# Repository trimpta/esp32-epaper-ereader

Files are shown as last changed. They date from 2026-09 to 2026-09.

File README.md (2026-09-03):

# esp32-epaper-ereader

> 🤖 **Disclosure: this project is "vibe coded."** The firmware, converter, simulator, docs, and
> this README were written collaboratively with [Claude](https://claude.com/claude-code) (Anthropic),
> directed and reviewed by a human, without physical access to the target hardware. Nothing here has
> run on a real board yet — see [Status / what needs real-hardware verification](#status--what-needs-real-hardware-verification)
> for the specific things that are reasoned-through rather than measured. Treat pin mappings, driver
> compatibility, and size estimates as a well-researched starting point to verify, not a guarantee.

A DIY EPUB e-reader built on the [CrowPanel ESP32 2.13" E-Paper HMI Display](https://www.elecrow.com/crowpanel-esp32-2-13-e-paper-hmi-display-with-122-250-resolution-black-white-color-driven-by-spi-interface.html)
(ESP32-S3, SSD1680Z/JD79661, 122×250 mono, 8MB flash, no SD slot) — full firmware, a browser-side
EPUB converter, a parametric enclosure, and a **fully-interactive browser simulator** so you can
build and preview the whole reading experience before your hardware even ships.

Not aiming for EPUB spec compliance — CSS, embedded fonts, images, and complex layout are
intentionally dropped. The goal is fast, low-effort page turns on very limited hardware, and a
project you can actually finish.

## The hardware

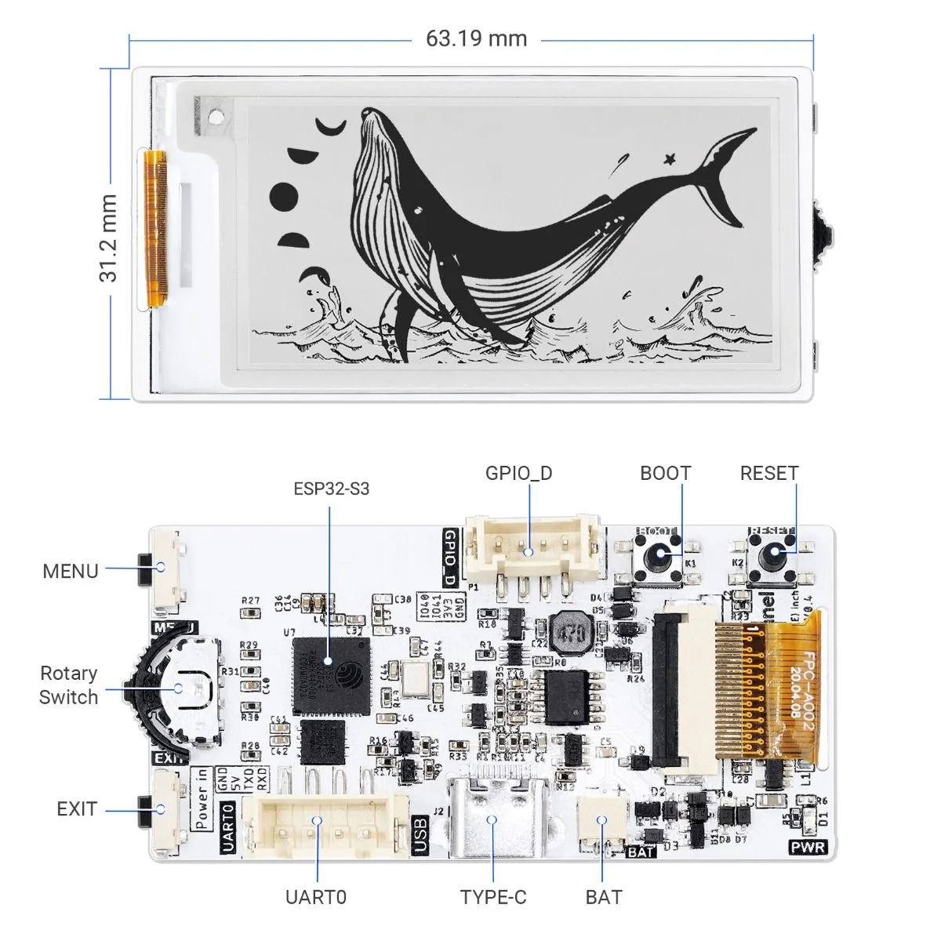
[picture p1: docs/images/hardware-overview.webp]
CrowPanel ESP32 2.13" E-Paper HMI Display — front view with dimensions, and the back of the PCB with its components labelled


<sub>Product image © [Elecrow](https://www.elecrow.com/crowpanel-esp32-2-13-e-paper-hmi-display-with-122-250-resolution-black-white-color-driven-by-spi-interface.html) — not a photo of this build. Real photos of the assembled reader are in [Coming soon](#coming-soon).</sub>

Two things on that board shape most of this project:

- **The 63.19 × 31.2 mm active area.** That's tiny — about 38 characters per line at the font size
  this uses, and only ~19 if you turned it portrait, which is why the UI is landscape-only. It's
  also the exact figure the simulator's [true-size calibration](docs/SIMULATOR.md#true-size-calibration)
  renders against, so the preview matches the real panel rather than just looking plausible.
- **Three inputs: MENU, EXIT, and a rotary switch** (which has its own push-click, giving six
  gestures once you count short vs. long presses). Every screen in the reader — menus, settings,
  all five games — is built to be driven by just those.

Note the `BAT` connector is a power input only: the schematic has no battery-voltage sense line to
the MCU, which is why there's no battery indicator anywhere in the UI. See
[docs/SIMULATOR.md](docs/SIMULATOR.md#deliberately-not-simulated-battery-percentage) for the
two-resistor fix if you want one.

## Try it without any hardware

`simulator/sim.html` is a self-contained, single-file browser app that mimics the real device —
same pagination logic as the converter, the same rotary/MENU/EXIT input model, and an accurate
e-ink partial-refresh/ghosting simulation — so you can load a real EPUB and see exactly how it will
look and behave on the panel.

```bash
cd simulator
python -m http.server 8420
# open http://localhost:8420
```

**[Try the simulator →](https://trimpta.com/esp32-epaper-ereader/sim.html)** ·
[Flash a board from your browser →](https://trimpta.com/esp32-epaper-ereader/install.html) ·
[Docs →](https://trimpta.com/esp32-epaper-ereader/docs.html)

The `simulator/` folder is the whole published site, not just the simulator: `index.html` is the
landing page, `sim.html` the simulator, `install.html` a Web Serial firmware installer, and
`docs.html` renders everything in `docs/`. GitHub Actions builds the firmware and deploys all of it
together.

| Reading | Library | Menu |
|---|---|---|
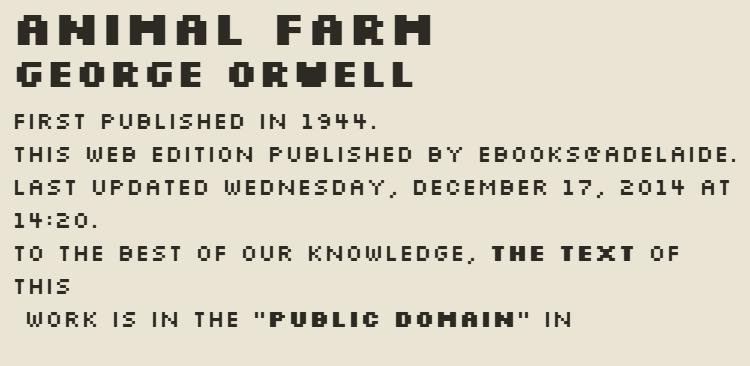
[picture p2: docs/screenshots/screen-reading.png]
Reading a page
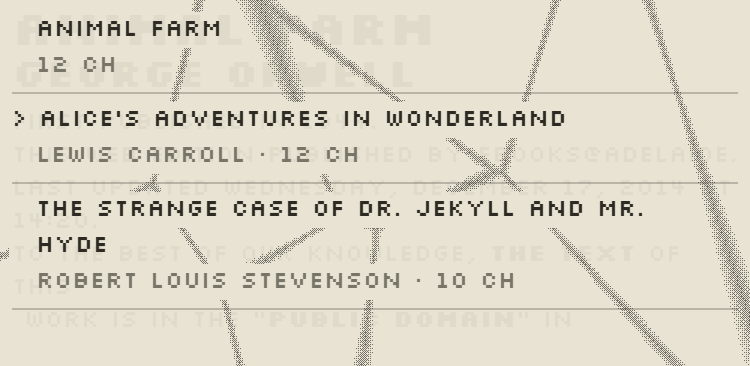
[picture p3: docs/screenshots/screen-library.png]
Library screen
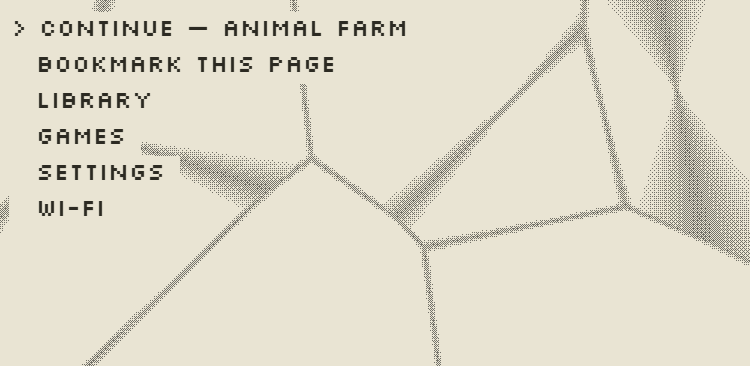
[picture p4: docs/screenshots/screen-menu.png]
Home menu
|  |  |  |

| Settings | Hangman | Sleep wallpaper |
|---|---|---|
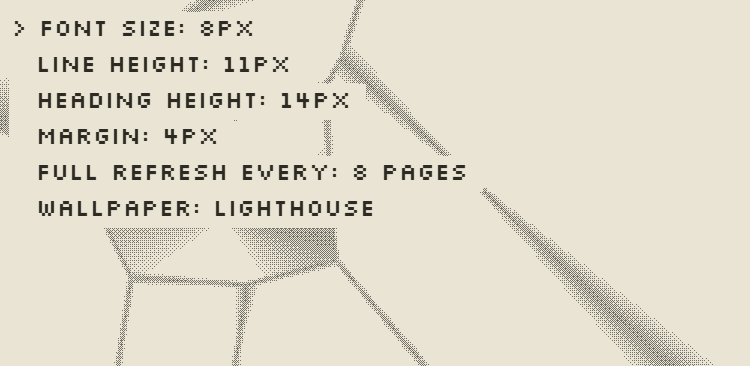
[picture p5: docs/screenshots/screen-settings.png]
Settings screen
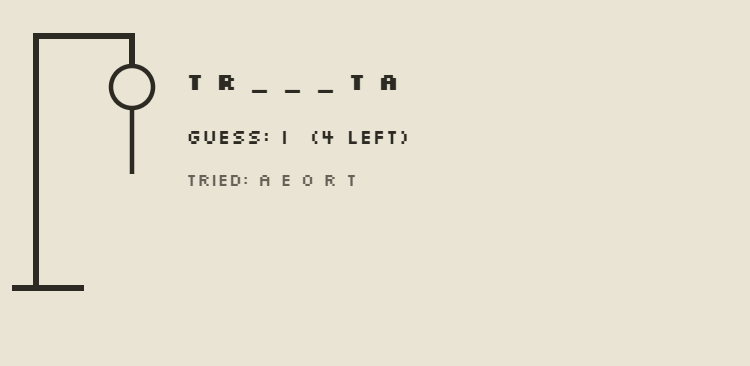
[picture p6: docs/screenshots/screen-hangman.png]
Hangman game
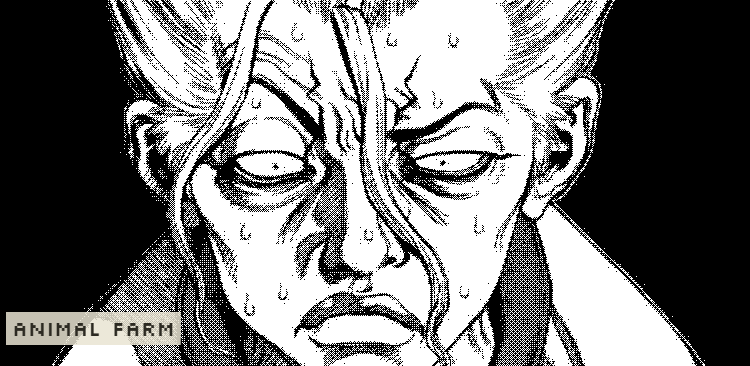
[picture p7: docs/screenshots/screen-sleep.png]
Sleep wallpaper
|  |  |  |

### What the simulator covers

- **Real pagination** — the exact tag-stripping/line-wrap/paginate logic the converter uses,
  rendered against the same font metrics the firmware will draw with.
- **Accurate e-ink behavior** — partial-refresh ghosting accumulation, periodic full-refresh
  flash sequences, and a long-press-MENU "force full refresh" — the same visual quirks a real
  EPD panel has, not a clean LCD redraw.
- **The real input model** — rotary scroll to move, short/long click on MENU, EXIT, and the
  rotary dial itself (six distinct gestures total, matching the schematic's actual GPIOs), mapped
  to mouse/touch so it works on desktop and mobile.
- **A two-layer menu** — MENU opens the current book's own menu (chapters, bookmarks, resume);
  EXIT opens the general home menu (library, settings, Wi-Fi, games) — so jumping chapters while
  reading doesn't require backing all the way out.
- **Scrub-to-edit numeric settings** — long-press the rotary to enter edit mode and dial a value
  in directly, or just keep tapping +1/-1 like before.
- **Five built-in games** — Lights Out, Minesweeper, Sudoku, Tic-Tac-Toe (real minimax AI), and
  Hangman, all built on the same rotary-cursor/MENU-select input pattern as the reader itself.
- **A wallpaper system** — pick from built-in wallpapers or upload your own from the web panel,
  with fit (cover/contain/stretch), pan, brightness, contrast, and invert controls on a live
  preview before it's committed; dithering to the panel's real 1-bit palette happens client-side,
  and only the ~3.7KB dithered bitmap is ever treated as what "reaches the device."
- **Per-book reading stats** — progress, pages read today, average pages/day, an estimated
  days-to-finish, and cumulative time spent reading, computed from a small per-day log rather than
  invented numbers.
- **A live memory panel** — real `.cebk`-equivalent byte accounting against the actual
  `firmware/partitions.csv` budget, not a placeholder estimate.
- **True-size calibration** — a ruler overlay with an adjustable slider so you can match the
  on-screen size to a real ruler and get an honest preview of the panel's actual footprint.

See [docs/SIMULATOR.md](docs/SIMULATOR.md) for the full UI/UX reference (input mapping, screen
hierarchy, every simulator-only affordance and how it maps — or doesn't — to real firmware).

## The enclosure

A two-part printable case in `enclosure/case.scad`, parametric and dimensioned from Elecrow's
own CAD assembly rather than guessed — see
[enclosure/reference/BOARD_GEOMETRY.md](enclosure/reference/BOARD_GEOMETRY.md) for the
measurements and how they were extracted.

| Printed parts | Controls | Assembled |
|---|---|---|
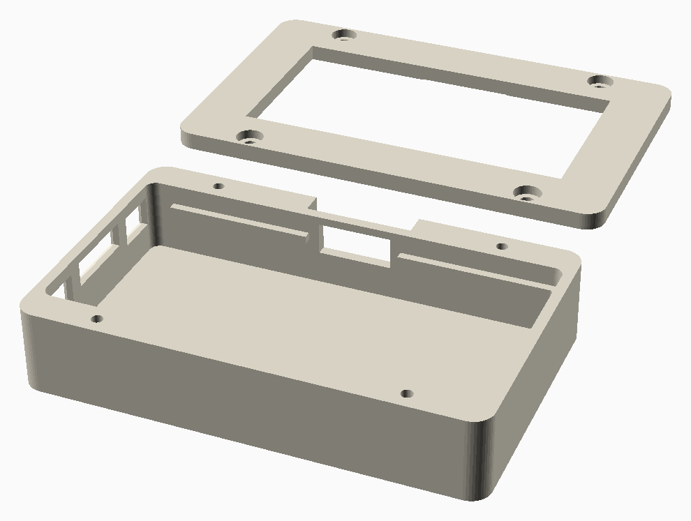
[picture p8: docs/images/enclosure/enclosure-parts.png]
The two halves of the case laid out flat as they would print
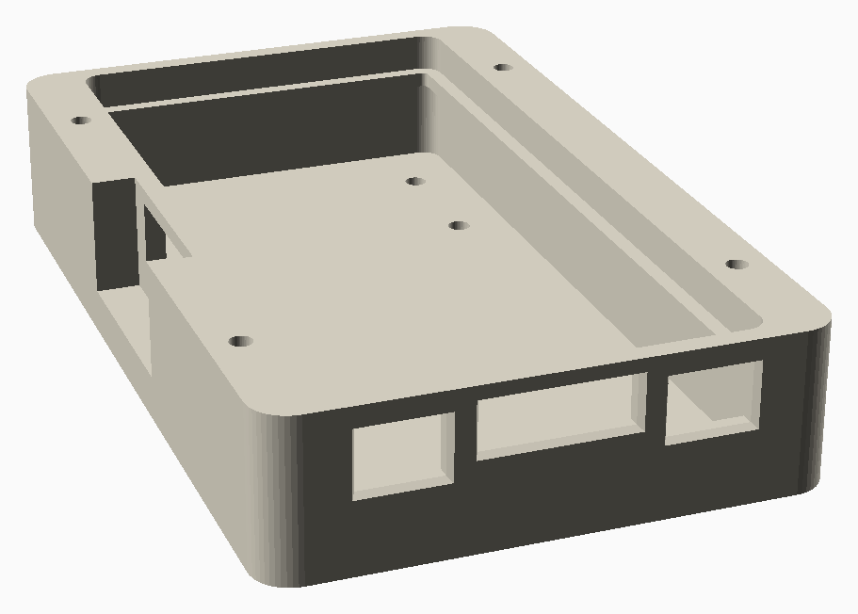
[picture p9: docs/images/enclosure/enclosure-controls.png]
The shell's end wall, with openings for MENU, the rotary wheel and EXIT
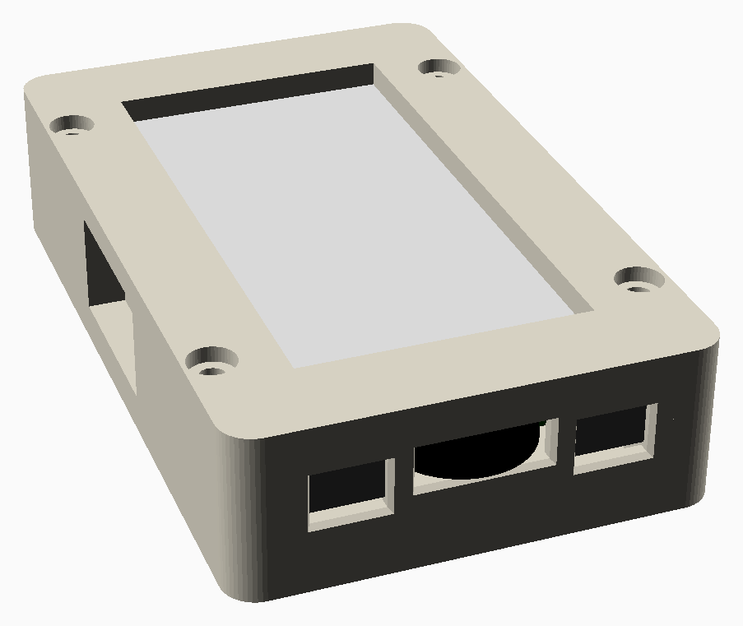
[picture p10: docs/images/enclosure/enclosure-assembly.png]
The closed case with the board mocked up inside, e-paper visible through the aperture
|  |  |  |
| Both halves, print-side down, no supports needed | MENU · rotary · EXIT come through one end wall | Closed, 67.2 × 42.0 × 15.2 mm |

Two things worth knowing before printing:

- **The board has no mounting holes.** It's held by a 0.8 mm ledge and an opposing rib, both
  interrupted where components reach the board edge — not screwed down. (An earlier revision of
  the reference file mistook the outline's corner fillets for Ø2 mounting holes; they aren't.)
- **No button extenders.** The rotary's rim ends up 0.75 mm proud of the wall; MENU and EXIT sit
  1.2 mm behind a 6.4 × 4.6 mm opening, which a fingertip reaches into directly.

These are renders, not photographs — nothing has been printed yet, and the case has never been
test-fitted to a physical board.

## How the reader itself works

```
   EPUB file                  browser (converter/)                ESP32 (firmware/)
 ┌───────────┐   unzip/parse   ┌──────────────────────┐   POST    ┌───────────────────┐
 │  book.epub│ ──────────────▶ │ strip tags, keep      │ /upload  │  LittleFS: *.cebk  │
 └───────────┘                 │ b/i/h1/h2, precompute │ ───────▶ │  renderer: seek +  │
                                │ line + page breaks    │          │  draw, no layout   │
                                │ against real font     │          │  work on device     │
                                │ metrics → .cebk file  │          └───────────────────┘
                                └──────────────────────┘
```

All the expensive work (unzipping, XML parsing, line-wrapping, pagination) happens once, in the
browser, using the same font metrics the device renders with. The ESP32 never parses EPUB/XML —
it just seeks into a flat binary and blits precomputed lines. See [docs/FORMAT.md](docs/FORMAT.md)
for the exact layout and [docs/ARCHITECTURE.md](docs/ARCHITECTURE.md) for the full pipeline and
the reasoning behind the design choices (transport, refresh strategy, storage constraints).

## Repo layout

- `simulator/` — the published website, deployed as-is to GitHub Pages:
  - `sim.html` — standalone browser preview of the on-device reading UI (no hardware needed): same
    tag-stripping/wrap/paginate logic as the converter, rotary→scroll and MENU/EXIT→LMB/RMB input
    mapping, live layout-parameter sliders, games, wallpapers, and a memory/calibration panel.
  - `index.html` — the landing page (what this is, features, setup).
  - `install.html` — Web Serial installer that flashes a connected ESP32-S3 from the browser.
  - `docs.html` — renders every doc below in full, with an index to switch between them.
  - None of this is on the device: `firmware/data/index.html` is the small book-upload page the
    ESP32 itself serves, and it's a separate file entirely.
- `converter/` — browser-side EPUB → `.cebk` converter (JSZip + vanilla JS). Runs standalone or
  loaded from the page the device itself serves.
- `docs/FORMAT.md` — the `.cebk` binary format spec (must stay in sync between converter and firmware).
- `docs/ARCHITECTURE.md` — pipeline, transport, refresh/pagination strategy, known open questions.
- `docs/FLASH_BUDGET.md` — verified flash/RAM accounting: what fits, what doesn't need porting,
  and roughly how many books fit once firmware and wallpapers are accounted for.
- `docs/SIMULATOR.md` — full UI/UX reference for the simulator (input mapping, screen hierarchy,
  every feature and how it relates to real hardware).
- `docs/FIRMWARE_REVIEW.md` — what a full firmware review + real compile found, and where the
  device and the simulator now match feature for feature.
- `docs/HARDWARE_DIVERGENCES.md` — everywhere the browser preview deliberately differs from the
  physical panel, and what each difference costs.
- `docs/ABOUT.md` — what this project is, the AI-assistance disclosure, sources and inspirations.
- `firmware/` — PlatformIO/Arduino project for the ESP32-S3: WiFi provisioning, upload server,
  book storage, e-paper renderer, button/rotary input, `partitions.csv`.
- `tools/dump_font_metrics/` — one-time Arduino sketch that dumps the *actual* on-device glyph
  widths over Serial, so the browser converter paginates using real metrics instead of guesses.
- `enclosure/` — parametric OpenSCAD case, dimensioned from Elecrow's CAD assembly (`reference/`
  holds the measurements and the extraction recipe). Clamps the board rather than screwing it
  down, because the board has no mounting holes.

## Status / what needs real-hardware verification

This was built without physical access to the board, so a few things are marked `TODO(verify)` in
code and need confirming against the actual PCB before they'll work:

- Exact SPI pin mapping for the display (CS/DC/RST/BUSY) — not published in Elecrow's docs, only
  the button/rotary GPIOs were (`firmware/src/config.h` has those).
- Whether [GxEPD2](https://github.com/ZinggJM/GxEPD2) supports the JD79661 driver variant, or
  whether Elecrow's own EPD library has to be used instead. Every GxEPD2 call is confined to
  `firmware/src/renderer.cpp` — menus and games draw through `Renderer`, never the display object
  — so swapping the backend stays a one-file change.
- Real glyph widths from `tools/dump_font_metrics` — `converter/font-metrics.example.json` is a
  placeholder and pagination will drift from what's actually rendered until replaced.
- Whether the `ext1` wake pin set is valid on this board, which is what gates real power saving
  between page turns (`firmware/src/input.h`).

The firmware itself now **compiles** against ESP32 Arduino core 3.3.10 — that build is what
caught the display-init bug and several others; see
[docs/FIRMWARE_REVIEW.md](docs/FIRMWARE_REVIEW.md). It still hasn't run on a board.

## Sources & inspirations

- **Hardware:** [Elecrow CrowPanel ESP32 2.13" E-Paper HMI Display](https://www.elecrow.com/crowpanel-esp32-2-13-e-paper-hmi-display-with-122-250-resolution-black-white-color-driven-by-spi-interface.html).
  The annotated board image in [The hardware](#the-hardware) is Elecrow's own product image,
  reproduced here for reference; their published schematic is also where the GPIO assignments in
  `firmware/src/config.h` come from.
- **Precedent projects** (see [docs/ARCHITECTURE.md](docs/ARCHITECTURE.md) for how this one differs):
  [atomic14/diy-esp32-epub-reader](https://github.com/atomic14/diy-esp32-epub-reader) does
  equivalent tag-stripping on-device; [Soldered's Inkplate 6FLICK](https://soldered.com/product/soldered-inkplate-6flick-e-paper-board/)
  pre-converts EPUBs with a host-side Python script before they reach the device — this project
  follows that second pattern, but in the browser and with pagination also moved off-device.
- **Firmware libraries:** [GxEPD2](https://github.com/ZinggJM/GxEPD2),
  [U8g2_for_Adafruit_GFX](https://github.com/olikraus/U8g2_for_Adafruit_GFX),
  [Adafruit GFX Library](https://github.com/adafruit/Adafruit-GFX-Library),
  [WiFiManager](https://github.com/tzapu/WiFiManager),
  [ESPAsyncWebServer](https://github.com/esphome/ESPAsyncWebServer) /
  [AsyncTCP](https://github.com/esphome/AsyncTCP) (esphome forks), [ArduinoJson](https://arduinojson.org/).
- **Converter:** [JSZip](https://stuk.github.io/jszip/) for standalone EPUB unzipping outside the simulator.
- **Fonts:** [Silkscreen](https://fonts.google.com/specimen/Silkscreen), [IBM Plex Mono, and IBM Plex Sans](https://fonts.google.com/specimen/IBM+Plex+Sans) (Google Fonts).
- **Sample books:** *Alice's Adventures in Wonderland*, *The Strange Case of Dr. Jekyll and Mr.
  Hyde*, and *The Wonderful Wizard of Oz* — all genuinely US-public-domain texts via
  [Project Gutenberg](https://www.gutenberg.org/), used as real conversion-pipeline test input
  rather than placeholder text.

## Coming soon

Real hardware photos, an assembly walkthrough, and side-by-side simulator-vs-actual-panel
comparison shots will go here once the `TODO(verify)` items above are closed out against a
physical board.

## Building one yourself

1. Order the [CrowPanel ESP32 2.13" E-Paper HMI Display](https://www.elecrow.com/crowpanel-esp32-2-13-e-paper-hmi-display-with-122-250-resolution-black-white-color-driven-by-spi-interface.html).
2. Poke around the [simulator](#try-it-without-any-hardware) — load your own EPUB, try the games,
   pick a wallpaper, get a feel for the actual reading experience before committing to anything.
3. Skim [docs/ARCHITECTURE.md](docs/ARCHITECTURE.md) and [docs/FORMAT.md](docs/FORMAT.md) to
   understand the conversion pipeline, then [docs/FLASH_BUDGET.md](docs/FLASH_BUDGET.md) for what
   fits on the device.
4. Flash `firmware/` with PlatformIO once your board is in hand (see `TODO(verify)` notes above —
   pin mapping and the EPD driver variant need confirming against your specific unit first).
5. Print or laser-cut `enclosure/case.scad`.

Issues and PRs welcome, especially real-hardware findings that close out the `TODO(verify)` items.

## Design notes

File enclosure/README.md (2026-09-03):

# Enclosure

`case.scad` is a parametric OpenSCAD case for the CrowPanel ESP32 2.13" E-Paper HMI
Display. **The dimensions are measured, not guessed.** They come from Elecrow's own CAD
assembly (`00-2-13_view_asm.stp`, in the `3D file` folder of
[Elecrow-RD/CrowPanel-ESP32-2.13-E-paper-HMI-Display-with-122-250](https://github.com/Elecrow-RD/CrowPanel-ESP32-2.13-E-paper-HMI-Display-with-122-250)),
opened in FreeCAD and queried part by part. The write-up is in
[`reference/BOARD_GEOMETRY.md`](reference/BOARD_GEOMETRY.md); the raw dump of all 519
solids is in `reference/step_parts_dump.json`.

Every position was then re-measured independently off `docs/images/hardware-overview.webp`
by pixel analysis, using the board outline as the scale reference. The two methods agree
to better than 0.4 mm on every control. Where they disagree, the CAD data wins.

## The board, in one table

| | |
|---|---|
| PCB outline | **31.2 x 63.2 mm**, 2.1 mm thick, 1 mm corner radius |
| e-paper module | 29.2 x 59.2 mm, standing 0.9 mm proud of the display face |
| Active area | 23.71 x 48.55 mm (122 x 250 px at 0.1942 mm pitch) |
| Mounting holes | **none** — see below |

## Which wall carries what

The board's long axis is horizontal in use (the firmware runs `setRotation(1)`).

- **Left wall** — MENU, rotary wheel, EXIT, at measured centres of −11.15, 0 and
  +11.15 mm across the board's width. All three are edge-mounted, actuate along the
  board's −Z, and physically stick out past the PCB outline: the rotary by 2.75 mm, MENU
  and EXIT by 0.8 mm each. They get wall openings, not face holes.
- **Bottom wall** — USB-C only, centred lengthwise (board Z = +0.60), flush with the
  board edge. The 5 mm-thick long wall is locally recessed back to 1.6 mm around the
  port so a plug can actually seat: the socket mouth is flush with the PCB edge, so every
  millimetre of wall eats into plug engagement.
  UART0 and BAT deliberately get **no** exterior cutout — UART0 is a debug/flashing
  console, and BAT is a JST pigtail meant to be plugged in before the case is closed.
  Revisit if you want battery hot-swap without opening the case.
- **Back floor** — **both** a BOOT pinhole and a RESET pinhole, Ø1.8 mm, paperclip-sized.
  These two switches are not on any edge: they sit 1.4 mm inboard of the board's top edge
  and protrude 6 mm out of the *component* face, so they are pressed from behind, through
  the floor, not from a side.
- **Front frame** — the screen aperture, and nothing else.
- **Top wall, right wall** — nothing but the case screws.

## Two printed pieces

- `back_shell()` — the tray. Owns the four walls, the left-wall openings, the USB-C
  opening and its recess, the two floor pinholes, the PCB support ledge, and the four
  screw bosses. Behind the board is a **flat, uniform-depth 8 mm cavity** — no battery
  pocket, no ribs, no raised island. A cell just lies in whatever space the components
  leave.
- `front_frame()` — a flat plate with the screen aperture and a clamp rib that holds the
  PCB down against the shell's ledge.

**There are no button extenders, plungers or actuator pieces, on purpose.** The reach
numbers work out without them:

- the rotary wheel's rim ends up **0.75 mm proud of the outer wall face**, so a thumb
  reaches it directly;
- MENU and EXIT end up **1.2 mm recessed** behind the outer face, and their openings are
  6.4 x 4.6 mm against a nub that is about 2.9 x 0.8 mm — a fingertip enters the opening
  and deforms well past 1.2 mm to reach the switch.

If you want a flusher feel on MENU/EXIT, deepen `OP_CHAMFER` or drop `WALL` to 1.2. Do
not add a plunger.

## The board has no mounting holes

`reference/BOARD_GEOMETRY.md` originally reported four Ø2.0 mm mounting holes at
(±14.60, ±30.60). Those cylindrical faces are real, but they are the PCB outline's
**corner fillets**, not holes — a Ø2.0 hole centred 1.0 mm from the edge would be tangent
to that edge, three of the four positions sit under the MENU/EXIT switch bodies, and the
product photo shows plainly rounded corners and no holes. (The "two Ø1.0 mm holes at
(±7.00, 30.30)" are likewise the rounded ends of the FPC pass-through slot.) That file
now carries the correction.

So the board is **clamped, not screwed**: it rests on a 0.8 mm perimeter ledge in the
shell and is held by a matching rib on the frame directly opposite, both interrupted
wherever a measured component would foul them. The two case halves screw to each other
with four **M2 x 8 self-tapping screws** driven from the front into the thickened long
walls, entirely outside the PCB footprint. That thickening is why the case is 42.0 mm
wide for a 31.2 mm board — with buttons on one short end and USB-C flush on one long
edge, the long walls are the only place a screw can live.

Overall closed size: **67.2 x 42.0 x 15.2 mm**.

## Verifying a change

`case.scad` carries its own verification geometry. Nothing here needs the physical board.

```sh
SCAD="C:/Program Files/OpenSCAD/openscad.exe"

# 1. Geometric check. `probes()` is the volume each control must have to itself:
#    the MENU/EXIT nubs swept outwards, the rotary's FULL swept disc (so this
#    tests rotational clearance, not just a hole), a USB-C plug, and two
#    paperclips. The intersection with the case must come out EMPTY.
"$SCAD" -o /tmp/interference.stl -D 'PART="interference"' case.scad
#    -> "Current top level object is empty" / a 47-byte STL means it passed.

# 2. Visual check. Orthographic elevations, not isometric — isometric is
#    ambiguous about which opening is where.
"$SCAD" -o left.png   --projection=o --camera=0,0,7,90,0,270,58  -D 'PART="shell"' case.scad
"$SCAD" -o floor.png  --projection=o --camera=0,0,7,180,0,0,110  -D 'PART="shell"' case.scad
"$SCAD" -o top.png    --projection=o --camera=0,0,7,0,0,0,110    -D 'PART="shell"' case.scad

# 3. Eyeball the parts in context, with the measured board and the probes drawn in.
"$SCAD" -D 'PART="assembly"' case.scad
```

The interference check is only worth trusting if it is sensitive, so confirm it: nudging
`probes()` by 1.2 mm in z or 2.0 mm in y turns the empty result into a 28 KB / 67 KB STL.

## Print settings

0.2 mm layer height, 3 perimeters, 15–20% infill. No supports needed in the orientation
the file lays the parts out in (`PART="plate"`): the shell prints floor-down and the
frame prints face-down. PETG or PLA are both fine; PETG if it will sit somewhere warm.

Watch two thin features when slicing: the ~1 mm of wall left between the flared mouths of
the MENU and rotary openings, and the ~1 mm of wall above the USB-C opening. Both are
above the 0.4 mm nozzle's comfortable minimum but do not shrink them further without
re-running the checks above.

## What the measured data still does not answer

- Component **heights** above the component face, beyond the bounding boxes. Enough for
  clearance, not enough for a snug fit — so how much of the 8 mm cavity a battery can
  actually use is unknown until you have the board in hand.
- The **active area's offset within the glass**. Only its size is derivable. The frame
  aperture is therefore the active area plus 1 mm all round.
- Whether the FPC ribbon bulges past the board's right-hand edge as it folds through its
  slot. The STEP says no (the module's bbox stops 1.15 mm short); the photo is
  ambiguous. `CLEAR` is 0.4 mm, which should absorb it.

## Prior art worth looking at

- [Case for CrowPanel 2.13" Epaper (Printables)](https://www.printables.com/model/1566902-case-for-crowpanel-213-epaper/related) —
  built for this exact board, a plain two-part protective shell with no battery bay.
- [Enclosure for CrowPanel ESP32 4.2" (Printables)](https://www.printables.com/model/1482686-enclosure-for-a-crowpanel-esp32-42inch-e-paper-dis/related) —
  wrong board, but explicitly built to cover the switches and hide a battery, so it is
  useful as a layout reference only.

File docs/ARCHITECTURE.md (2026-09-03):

# Architecture

## Pipeline

1. **Browser converter** (`converter/`) unzips the EPUB with JSZip, walks `container.xml` → the
   OPF (manifest + spine) → each spine XHTML file with `DOMParser`. Everything except paragraph
   breaks, `h1`/`h2`, `b`/`strong`, `i`/`em` is discarded — no CSS, no images, no embedded fonts.
2. The converter line-wraps and paginates using **real glyph widths** dumped from the device
   (`tools/dump_font_metrics`), so the page breaks it computes are exactly what the firmware will
   render — the device does no text-layout work at runtime, just seeks and draws.
3. Output is a single `.cebk` file (`docs/FORMAT.md`). The converter can download it locally or
   `POST /upload` it straight to the device over the same connection it's being served from.
4. **Firmware** (`firmware/`) stores `.cebk` files in LittleFS (no SD slot on this board — 8MB
   flash total, shared with the firmware image, so realistic capacity is a handful of books; this
   is the main reason the format strips so aggressively instead of keeping raw HTML/markup).
5. Rendering seeks to the requested page's line range and draws each line, applying bold/italic/
   heading fonts where a style run overlaps — no measuring, no XML, no ZIP on-device.

## Layout constants are compile-time, not a user setting

Margin, line height, and font size (`firmware/src/config.h`, mirrored in
`converter/converter.js`'s `LAYOUT`) have to match on both sides of the pipeline, because page
breaks are computed once at conversion time and baked into each `.cebk` file's line/page tables —
that's the whole basis for the device doing zero text-layout work at runtime (see above). Changing
one of these constants after books are already converted silently desyncs their saved tables from
whatever the new constants would actually render.

`simulator/sim.html`'s Layout Parameters sliders (and the on-device Settings screen) look like a
live user preference — they re-paginate instantly — but that's a design-time convenience for
picking values before they're hardcoded into `config.h` and flashed, not a runtime capability real
firmware has. If per-user adjustable text size ever becomes a real feature, it needs on-device
re-flow (the firmware shipping a word-wrap routine after all, run once when a setting changes
rather than on every page turn) — a deliberate scope decision, not implemented here.

## Why preprocessing happens off-device instead of on the ESP32

The ESP32-S3 has enough RAM to parse EPUB (there are on-device EPUB readers, see below), but
doing it there means shipping a ZIP inflator + XML parser in firmware and re-running layout on
every page turn (or caching pagination results in flash, which is the same problem this format
solves anyway). Since a browser is already in the loop for uploading, and has orders of magnitude
more CPU/RAM than the target device, it's strictly cheaper to do the one-time expensive work there
and hand the device a format it can render with zero computation.

Precedent: [atomic14/diy-esp32-epub-reader](https://github.com/atomic14/diy-esp32-epub-reader)
does the equivalent tag-stripping (keeps only `h1-h6`/`b`/`i`) on-device; Soldered's Inkplate
6FLICK reader uses a Python script on the host to pre-convert EPUBs before they reach the device.
This project follows the second pattern but in the browser instead of a desktop script, and pushes
pagination off-device too (neither precedent does that).

## Transport

- **Persistent STA WiFi + mDNS-less discovery.** The device joins a saved network (phone hotspot
  or home WiFi — same code path either way) instead of running its own AP that you'd have to
  switch to per upload. `.local` mDNS resolution is unreliable from Android browsers even on your
  own hotspot, so the device prints its assigned IP directly on the e-paper screen after
  connecting instead of relying on `ereader.local`.
- First-time (or re-)provisioning uses a captive portal (WiFiManager), entered only when there are
  no saved credentials or the MENU button is held at boot — not part of the normal flow.
- Reconnect uses retry-with-backoff rather than re-provisioning, since phone hotspots commonly
  sleep after inactivity and come back with the same SSID/password.

## Refresh strategy

E-ink partial refresh (~300ms) is used for every page turn; ghosting is cleared with a full
refresh every ~8–10 pages (same cadence convention as most commercial e-readers), tracked with a
simple counter rather than a timer, so it's tied to actual reading activity.

## Input

Rotary switch (`ROTARY_UP`/`ROTARY_DOWN`/`ROTARY_CONF`) maps directly to page turn / confirm with
no menu layer in between — that's the highest-frequency action and the only one worth optimizing
for zero indirection. MENU/EXIT are reserved for book list, TOC, and settings screens, which can
afford a slower full-refresh redraw since they're rare.

## Explicitly out of scope for v1

- Images, embedded fonts, CSS, footnotes/links, nested lists, tables.
- True italic bitmap glyphs — u8g2's stock font set has very little italic/oblique coverage at
  small sizes. v1 ships without a real italic face; see `firmware/src/renderer.h` for the
  placeholder and how to swap in a converted font later if it matters enough to generate one.
- On-device library management beyond list/delete — no metadata sync, no covers, no search.

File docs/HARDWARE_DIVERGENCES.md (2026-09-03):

# Where the simulator diverges from real hardware

The browser simulator is an honest preview of the reading experience, not an emulator. These
are the places where it deliberately differs from the device, and what the difference costs.

- **Font.** The screen uses a pixel web font (Silkscreen) measured live via Canvas — not the
  actual u8g2 glyph metrics the firmware draws with, so exact line breaks will shift slightly
  once `tools/dump_font_metrics` runs on real hardware.

- **Italic.** Shown as a synthetic slant for preview purposes. u8g2 has no real italic face at
  this size, so firmware falls back to regular — see [Architecture](ARCHITECTURE.md).

- **Refresh flash.** Modeled on real SSD1680/EPD behavior — full refresh flickers through a
  couple of black/white cycles (the datasheet-level description is "flickers multiple times,"
  vs. once for fast-refresh and never for partial), and partial refresh accumulates faint
  ghosting that only a full refresh clears. But it's a stylized per-pixel approximation, not
  the SSD1680's actual waveform LUTs — real timing and exact ghosting patterns will differ.
  Real full refresh also takes ~2-3s; the simulator speeds this up to stay pleasant to use.

- **Always landscape.** The panel is a 122×250 portrait sensor natively, but that's ~19
  characters/line — bad enough that portrait was never worth shipping as an option. Rendered
  rotated (250×122) unconditionally, matching `display.setRotation(1)` in
  `firmware/src/renderer.cpp`.

- **No battery indicator.** The stock schematic has no battery-voltage sense line at all, so
  the simulator doesn't show one — real hardware reads `-1` (unavailable) until a resistor
  divider is added. See `firmware/src/config.h` / `battery.cpp` for the two-resistor fix; the
  UI can show a real percentage once that's wired up.

- **Resume position, bookmarks and reading stats.** In the browser these live in
  `localStorage`, keyed by title+author — not in the book file. Re-loading the *same* EPUB
  (or the sample) restores where you left off. On device this is simpler: the book is already
  in flash, so `firmware/src/library.cpp` keeps one small `/state.json` record keyed by path,
  written debounced rather than on every page turn (flash write cycles being the one resource
  a per-turn write would actually burn).

- **Reading-stats clock.** The board has no RTC, so the device gets the date from NTP after
  WiFi connects. Anything read before that goes into an "unknown day" bucket instead of being
  filed under a guessed date. The simulator just asks the browser.

- **Layout parameters aren't a runtime setting.** Changing margin/line-height/font-size in the
  simulator re-paginates instantly because it's a design-time tool — the real device can't do
  that. Page breaks are precomputed once, at conversion time, and baked into each `.cebk`
  ([FORMAT.md](FORMAT.md)); the whole point was zero text-layout work on the ESP32. Change a
  constant in `firmware/src/config.h` after books are on the device and their saved page/line
  tables no longer match what gets rendered — every book has to be re-converted and
  re-uploaded. Use the sliders to pick final values, then hardcode them and reflash. The
  on-device Settings screen shows these values but doesn't offer to change them; what it
  *does* offer (full-refresh cadence, wallpaper) is genuinely runtime-safe.

- **Game cursor highlight.** The simulator inverts whatever is under the cursor using canvas
  `difference` compositing. A 1-bit panel can't composite, so the firmware draws the cursor in
  whichever color contrasts with the cell it's on — it always knows the cell's fill state, so
  the result is the same guaranteed-visible highlight, computed instead of composited.

- **Sleep wallpaper.** In the simulator, an image embedded directly in the page and dithered
  to the panel's real 1-bit palette (a real EPD can't show grayscale, so drawing it as a photo
  would misrepresent what this simulates). On device, a wallpaper is a raw 1-bit 122×250
  bitmap in `/wallpapers` — 3,813 bytes regardless of the source photo, see
  [Flash & RAM budget](FLASH_BUDGET.md).

- **Ghosting simulation itself.** A canvas can't physically ghost, so the simulator fakes it.
  Real firmware just calls GxEPD2's partial/full refresh and the physical panel ghosts on its
  own — there's no firmware counterpart to this code at all.

- **Fullscreen, touch, and haptics.** Browser affordances standing in for not having the
  device in hand. The real board has no touchscreen, no vibration motor, and is always
  "fullscreen" — it's a dedicated display, not a browser tab.

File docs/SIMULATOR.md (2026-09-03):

# Simulator UI/UX reference

`simulator/sim.html` is a single, self-contained browser page that mimics the on-device reading
experience: same pagination logic as `converter/`, the same three-input model as the real board
(thumbwheel + MENU + EXIT), and an approximation of e-ink's partial-refresh/ghosting behavior. This
doc is the complete reference for how it behaves — what maps to real firmware and what's
simulator-only scaffolding. See [Hardware divergences](HARDWARE_DIVERGENCES.md) for where the
preview deliberately differs from the panel, and [docs/ARCHITECTURE.md](ARCHITECTURE.md) for the
underlying pipeline this UI sits on top of.

## Input model

Real hardware has exactly three physical inputs: a thumbwheel (roll + its own push-click)
and two buttons, MENU and EXIT. Each of the three supports a **short** and a **long** press/click,
giving six distinct gestures — all six are wired up:

| Input | Short | Long (hold) |
|---|---|---|
| Wheel roll | move cursor / turn page (`doNext`/`doPrev`) | — (continuous, not a press) |
| Wheel click (CONF) | context action (`doConf`) — Minesweeper flag, Sudoku cycle-down, otherwise same as MENU | enter scrub **edit mode** on the focused numeric field (`tryEnterEditMode`) |
| MENU | `doMenu()` — see [the two-layer menu](#the-two-layer-menu) below | force a full refresh right now, bypassing the refresh-cadence counter |
| EXIT | `doExit()` — back out one screen (or open Home from the reading view) | put the device to sleep immediately |

In the browser, MENU is left-click, EXIT is right-click, and the wheel is its own click
target; all three are wrapped by a generic `bindHoldGesture(el, {onShort, onLong, holdMs})` helper
(Pointer Events, so mouse and touch share one code path) that fires `onShort` on release-before-the-hold-threshold
and `onLong` once the hold threshold is crossed. Every input funnels through `handleInput(kind)`,
which resets the idle-sleep timer first, then — if the device is asleep — treats the input as
*only* a wake signal, matching how a real e-reader doesn't act on the same button press that
woke it.

### Scrolling by touch

Scroll comes from a mouse wheel, or from dragging either the screen or the wheel graphic
(`bindDragScroll`). Three details, each of which was a bug report first:

- **The selection follows your finger.** Drag down, the cursor moves down. An earlier version
  used the content-scrolls-under-you model that web pages use (drag up to go forward), which
  reads fine for a page of text and backwards for a cursor — people reported "swipe up puts the
  cursor down". What's being moved on most screens is a selection, so the selection wins.
- **It's continuous, not one step per swipe.** Every `DRAG_STEP_PX` of travel emits a detent
  while the finger is still down, so a long drag runs down a list the way rolling the real wheel
  would.
- **Every control needs `user-select: none` and `touch-action: none`, not just the screen.**
  Without them Android starts its own long-press gesture on the buttons: the text-selection
  callout appears over the control, and the `pointercancel` that follows kills the hold timer —
  so "hold MENU" silently did nothing some of the time. `touch-action` also stops the browser
  claiming a drag as a page scroll before the handlers see it, which is what "swipe just scrolls
  the page" was. It's set on `.device` too, because fingers miss a 250px-wide screen constantly.

### It's a thumbwheel, not a knob

Worth being precise about, because the mockup got it wrong for a long time and that misled
people. The part (`XB-TM-2024A`) is a flat wheel lying in the board's own plane — 13.2 mm
across, poking 2.75 mm past the board edge, with a toothed rim you roll with a thumb. It is
**not** a rotary encoder shaft with a knob on top.

The simulator used to draw it as a circle with a pointer tick, which is exactly what an encoder
knob looks like: the wrong component, and it invited people to try turning something that
doesn't turn that way. It's drawn edge-on now, ridged, emerging from a slot — so the only
gesture the picture suggests is the one it actually has. It's also draggable, which it wasn't
before; on a phone a wheel that looks rollable and does nothing is worse than no wheel at all.

The wheel's click (`ROTARY_CONF`) is a genuine third input, and one of the few things here that
is **confirmed on physical hardware** — the owner checked a real board and it does press in,
on top of rolling. It also shows up twice in Elecrow's own material: as `TM_2024A` on the
schematic (pins `IO4_DOWN`/`IO6_UP`/`IO5_CONF`) and as `XB-TM-2024A` in their CAD assembly. So
the six-gesture model rests on three inputs that all definitely exist. It's a
harmless alternate "select" on plain list/menu screens (same as MENU), and only diverges from
MENU in Minesweeper (flag a cell) and Sudoku (cycle a digit downward instead of up).

## Screen hierarchy

Screens live on a stack (`state.screenStack`), pushed with `pushScreen(name)` and popped with
`popScreen()` — EXIT is generically "pop the stack" except from the reading view, which is
special-cased (see below). Nine of the screens are plain scrollable lists (`LIST_SCREENS`), each
just a title and a row-generator function; a shared renderer (`screenBlocks`/`selectableBlocks`/
`drawBlockList`) handles multi-line wrapped rows, separators, and scroll-into-view windowing so
list screens don't each reimplement scrolling.

```
reading ──MENU──▶ bookMenu ──"Browse chapters"──▶ bookChapters
   │                  │
   │                  ├──"Bookmarks (N)"──▶ bookmarks
   │                  └──"Reading stats"──▶ stats
   │
   └──EXIT──▶ home ──▶ library ──(pick a book)──▶ bookMenu
                  │
                  ├──▶ allStats   (whole library)
                  ├──▶ games ──▶ lightsout / minesweeper / sudoku / hangman / tictactoe
                  ├──▶ settings
                  └──▶ wifi
```

- **home** — Continue-reading shortcut (if a book is open) + Bookmark-this-page, then Library,
  Reading stats, Games, Settings, Wi-Fi.
- **library** — one block per book (wrapped title + author/chapter-count line, dimmed), with a
  separator between books. Replaces an earlier flat "every chapter of every book" list. Picking a
  book always goes to **bookMenu** rather than straight into reading, since a book with existing
  progress needs to ask continue-vs-restart either way.
- **bookMenu** — context menu for one specific book. Shape depends on whether it's the book
  currently open (`state.browseBookIdx === state.activeBook`): the open book gets a quick
  "Bookmark this page" row instead of Continue/Start (you're already there), everything else gets
  Continue (if it has saved progress) or Start reading, plus Browse chapters, Bookmarks, Reading
  stats, and a "More… (Library, Settings, Wi-Fi, Games)" escape hatch to Home.
- **bookChapters** — flat chapter list for the book in `state.browseBookIdx`; picking one jumps
  straight to page 1 of that chapter.
- **bookmarks** — per-book bookmark list; picking one jumps to that saved position.
- **stats** — read-only pace readout for the book in `state.browseBookIdx` (see
  [Reading stats](#reading-stats) below); every row is a display line, not a selectable action.
- **allStats** — the same idea across the whole library rather than one book, reached from Home.
- **settings** — layout sliders (font size, line height, heading height, margin, full-refresh
  cadence) plus the wallpaper switcher, all scrub-editable (see below).
- **wifi** — a fake connection-state screen (`state.wifiMode`), illustrating AP-mode-vs-connected
  copy; there's no real network code in the simulator.
- **games** — Lights Out, Minesweeper, Sudoku, Hangman, Tic-Tac-Toe. Each game is its own
  self-contained screen outside `LIST_SCREENS` with its own draw/input handlers, but shares the
  rotary-cursor/MENU-select/EXIT-leave pattern with everything else.

### The two-layer menu

MENU and EXIT deliberately open two *different* menus from the reading view:

- **MENU → `bookMenu`** — the current book's own context menu (chapters, bookmarks, bookmark this
  page). This is the fix for a specific friction: jumping to another chapter used to mean
  MENU → Home → Library → re-find this same book → bookMenu → Browse chapters. Now it's one press.
- **EXIT → `home`** — the general menu (Library, Games, Settings, Wi-Fi), for when you actually
  want to leave the book rather than jump around inside it.

`state.browseBookIdx` is what a book-context screen (`bookMenu`, `bookChapters`, `bookmarks`)
actually reads; `doMenu()`'s `reading` case sets `browseBookIdx = activeBook` before pushing, so
those screens don't need a separate "is this the currently-open book" code path from the Library
entry point — only `bookMenuRows()`'s Continue-vs-Bookmark branch cares about the distinction, via
`browseBookIdx === activeBook`.

### Scrub-to-edit numeric settings

Long-pressing the rotary on a scrubbable row (any Settings slider, or the focused cell in Sudoku)
enters an edit-mode session (`state.editMode = {original, get, set, min, max, step}`):

- Rotary scroll adjusts the value directly (dial it in), instead of moving a list cursor.
- **MENU** commits the change and exits edit mode.
- **EXIT** reverts to the original value and exits edit mode.
- The status strip switches to `EDITING (value) · scroll to adjust · MENU saves · EXIT cancels`.

This coexists with the original press-to-cycle behavior — pressing MENU/CONF on a settings row
outside edit mode still steps the value by one increment (wrapping at min/max) the same way it
always did. A row only offers edit mode if it exposes a backing `.el` (the `<input type="range">`
element); the Wallpaper row deliberately has no `.el` (it cycles a name, not a number) and so is
correctly excluded from scrub editing — `tryEnterEditMode()` uses `.el`'s presence as exactly that
signal, nothing more elaborate.

## Refresh & ghosting simulation

E-ink doesn't repaint like an LCD, so the simulator models two distinct refresh types:

- **Partial refresh** (most page turns) is instant and flicker-free, but each one composites a
  faint darkening of whatever was inked in the *previous* frame onto the new one
  (`applyGhosting`) — this is what accumulates as visible ghosting the longer you go between full
  refreshes.
- **Full refresh** runs a short invert/normal/invert/normal flash sequence (`flashSequence`) before
  drawing the new content, clearing all accumulated ghosting. It happens automatically every N
  page turns (the Settings "Full refresh every" slider, `state.layout.fullRefreshEvery`), tracked
  by a counter rather than a timer so it's tied to actual reading activity, not wall-clock time.
- **Long-press MENU** forces a full refresh immediately, bypassing the cadence counter — for when
  ghosting has built up and you don't want to wait for the next automatic one.

This is a stylized per-pixel approximation (luminance blending), not the SSD1680's real waveform
LUTs — exact timing and ghosting patterns will differ on real hardware, and real full refresh takes
roughly 2-3 seconds (sped up here to stay pleasant to use in a browser).

## Reading stats

`bookMenu`'s "Reading stats" row opens a per-book pace readout: progress (pages read / total,
with a percentage), pages read today, an average pages/day figure, an estimated days-to-finish,
and cumulative time spent reading that book. All of it is derived from data the simulator was
already tracking (page position, a book's total page count) plus one new small log
(`readingLogFor`/`bookReadingStats` in `simulator/sim.html`): one `{pages, seconds}` bucket per
calendar day per book, in its own `localStorage` key (see [Persistence](#persistence)).

- **Pages** only increments on a forward page turn while that book is the one open and on
  screen (`logPageTurn`, called from `doNext()`) — paging backward to re-read something doesn't
  count as progress, so it can't be inflated by flipping back and forth.
- **Seconds** accumulates from a 5-second heartbeat that only counts time while a book is
  actually on screen, awake, and the tab is visible (`document.visibilityState`) — not while
  asleep, not while browsing menus or playing a game with a book still "open" underneath. Each
  tick is capped at 2× the interval so a laptop suspending mid-session with the tab left open
  can't log an hour of "reading" in one jump.
- **Average pages/day** divides total logged pages by the number of *days with any logged
  activity*, not calendar days since the book was first opened — taking a week off doesn't punish
  the average, it just doesn't move it. Estimated days-to-finish divides remaining pages by that
  average; both read as "not enough data yet" until at least one day has been logged.
- The log is pruned to the most recent 120 days per book on write, so it can't grow unbounded in
  `localStorage`.

This is now ported: `firmware/src/library.cpp` keeps the same per-day `{pages, seconds}` buckets,
capped at 14 days rather than 120 and written debounced instead of on every page turn, because
LittleFS write cycles are a real constraint the browser's `localStorage` doesn't share. The device
has no RTC either, so days are keyed off NTP time once WiFi connects and anything read before that
lands in an explicit "unknown day" bucket rather than a guessed date.

### Across the whole library

Home → **Reading stats** (`allStats`) answers a different question from the per-book screen: not
"how is this book going" but "how much am I reading". `overallReadingStats()` in the simulator and
`library::overallStats()` on the device both merge every book's per-day buckets into one timeline
first, then report today, all-time, average pace, streak, days read, and how many books are in
progress versus finished.

Two deliberate choices, matched on both sides:

- It reads the **whole log**, not just the currently-loaded library, so a book you've since
  removed still counts toward all-time totals — the reading happened either way. In-progress and
  finished counts are the exception: those only mean anything for books actually present, so they
  come from the library instead.
- The **streak** counts back a day at a time from today, and if today has nothing logged yet it
  starts from yesterday — a streak shouldn't read as broken until a whole day has actually been
  missed. On device the "unknown day" bucket counts toward totals but is excluded from the streak,
  which needs real dates to mean anything.

## Wallpapers

Shown only on the sleep screen. `BUILTIN_WALLPAPERS` ships one built-in image (`lighthouse`,
sourced from `assets/wallpapers/lighthouse.webp` and embedded as a data URI); the web panel's
"Add wallpaper…" upload lets you add more at runtime. Either way, the *source* image is dithered
to the panel's real 1-bit palette client-side (Bayer 4×4 ordered dithering, `ditherImageToPanelCanvas`)
before it's ever treated as a real wallpaper, and cached per-id (`wallpaperCache`) — the simulator
only ever treats the resulting dithered bitmap as "what reaches the device," discarding the
original source once you confirm an upload, because that's the honest cost model: a real panel
can't show grayscale, and the actual firmware would only ever store the finished 1-bit bitmap
(122×250/8 = 3,813 bytes, regardless of how large or colorful the source photo was — see
[docs/FLASH_BUDGET.md](FLASH_BUDGET.md#wallpapers-cheap-by-design)). The in-device Settings screen
cycles between whichever wallpapers are currently available; the web panel additionally shows a
grid of thumbnails to pick from directly.

### Adjustable dithering on upload

A fixed threshold doesn't dither every photo well — a dim photo goes mostly black, an overexposed
one goes mostly white, and a photo's interesting part isn't always dead center. So uploading an
image doesn't commit it immediately: it opens a live preview (`wallpaperPreview`) with **Fit**,
**Pan X/Y**, **Brightness**, **Contrast**, and **Invert** controls, all re-dithering the same
source image in place (`renderWallpaperPreview` → `ditherImageToPanelCanvas`) so you can see the
actual 1-bit result while you adjust, not a grayscale approximation of it.

- **Fit** picks how the source image maps onto the panel's 250×122 frame: **Cover** (scale to
  fill, cropping whatever overflows — the default), **Contain** (scale to fit entirely inside the
  frame, letterboxed with blank space), or **Stretch** (fill exactly, ignoring aspect ratio).
- **Pan X/Y** slide the crop/letterbox window within the frame instead of always centering it —
  meaningful for Cover (which part of a wider/taller source gets kept) and Contain (where the
  letterboxed image sits); a no-op for Stretch, which has no leftover space to slide (the pan
  sliders disable themselves in that mode).

### Picking a dither by looking at it

There's no algorithm that's right for every image on a 1-bit panel: text and line art want a hard
threshold, photographs want error diffusion, and a smooth gradient wants an ordered matrix so it
doesn't break into worms. Rather than asking which one you want up front, the upload flow renders
**all five** from the same source and lets you click the one that looks best:

| Algorithm | Character |
|---|---|
| **Threshold** | Hard 50% cut. Line art, logos, text. |
| **Bayer 4×4** | Coarse ordered crosshatch — the default, and the most legible at this size. |
| **Bayer 8×8** | Finer grain, smoother gradients, softer edges. |
| **Floyd–Steinberg** | Classic error diffusion. Most detail, can read as noisy. |
| **Atkinson** | Diffuses only ¾ of the error, which is exactly what makes it crisper and higher-contrast. |

The comparison is only meaningful if everything *except* the algorithm is identical, so
`imageToPanelLuminance()` does the fit and tone-mapping once and each algorithm gets its own copy
of that buffer (`renderWallpaperPreview`). Changing Brightness/Contrast re-renders the whole set,
because which algorithm wins genuinely changes with the tone curve. The selected option's pixels
are also what gets committed — the full-size canvas is built from the same `ImageData` as its
thumbnail rather than re-dithered, so the two can't disagree.

The luminance buffer is `Float32Array`, not `Uint8`: the diffusion algorithms carry fractional
error between pixels, and rounding at every step visibly banded the result.

Only once you click "Use this wallpaper" does the currently-previewed dithered bitmap get
committed to `wallpaperCache` and the source image get discarded — clicking Cancel discards the
source without ever exposing it to `wallpaperCache` at all. These settings are per-upload, not
global: each wallpaper keeps whatever bitmap you confirmed for it, not a live reference back to
fit/pan/brightness/contrast values.

## Memory panel

The sidebar's Memory panel computes real `.cebk`-equivalent byte counts from each *currently
loaded* book's actual in-memory `lines`/`pageStarts`/`runs` arrays (per the layout in
[docs/FORMAT.md](FORMAT.md)) plus each wallpaper's fixed 3,813-byte bitmap cost, and compares the
total against the real `firmware/partitions.csv` LittleFS budget. This is a live measurement of
what's actually loaded in the simulator right now, not the FLASH_BUDGET.md doc's necessarily
approximate chars-per-line estimate (that doc reasons about *typical* books; this panel measures
the *specific* books you've loaded).

## True-size calibration

The "📏 True size" toggle overlays a millimeter-marked SVG ruler and a scale slider
(`rulerScale`, persisted to `localStorage` under `rotaryReaderRulerScale_v1`). CSS pixels have no
reliable physical-size meaning across devices/browsers, so instead of trusting an assumed DPI, you
place a real ruler against the screen and adjust the slider until the on-screen ruler matches it —
that gives an accurate px-per-mm conversion for your specific screen at its current zoom level.

By default that calibration only resizes the inert preview box in the calibration panel itself
(labeled with the panel's real 63.2×31.2mm active area). Checking **"Also resize the simulator's
actual display above to true size"** (`cTrueSizeDisplay`, persisted under
`rotaryReaderTrueSizeDisplay_v1`) applies the same calibrated size to the real, interactive
`#screen` canvas instead — overriding its normal "fill the sidebar column" CSS width via an inline
style (`applyTrueSizeDisplay`) so the whole reading/games/menu UI can actually be used at true
physical size, not just looked at in a same-size-as-nothing-else preview rectangle. This is
usually a *smaller* canvas than the default mockup size on typical screens, since 63.2mm is
genuinely small.

## Games

All five (Lights Out, Minesweeper, Sudoku, Hangman, Tic-Tac-Toe) reuse the same input pattern as
everything else — rotary moves a cursor, MENU acts on the focused cell/letter, EXIT leaves — rather
than introducing game-specific controls. Two notable details:

- **Cursor visibility.** Early versions drew the cursor as a same-color outline, which vanished
  against same-colored content (worst case: an "on" cell in Lights Out). All four grid-based games
  now use `invertCellHighlight()` (`ctx.globalCompositeOperation = 'difference'`), which inverts
  whatever's underneath — guaranteed visible regardless of the cell's own color.
- **Tic-Tac-Toe's AI is real minimax**, not a heuristic — "vs AI" means the best a perfect game
  gets you is a draw. The 3×3 board keeps the search space trivially small (well under a
  millisecond), so there's no reason to cut the corner with a weaker opponent.

## Fullscreen, mobile, and touch

The "⤢ Fullscreen" button fullscreens the device mockup only (not the whole page — the sidebar
panels have nothing to do once you're just looking at the screen), and best-effort locks screen
orientation to landscape where the browser supports it (mainly Android Chrome; silently a no-op
elsewhere). On touch devices, a rotate-to-landscape prompt is the reliable fallback for the same
goal. `bindHoldGesture` unifies mouse and touch input through Pointer Events, so every gesture
(short/long press) works identically with a mouse or a finger. Haptic feedback
(`navigator.vibrate`) fires on every input on browsers that support it (Android Chrome-family
only — iOS Safari and desktop browsers no-op harmlessly).

## Sleep & idle timing

`resetIdleTimer()` runs on every input and schedules `goToSleep()` after an idle period that
depends on context: 5 minutes while actively reading (a page sitting on screen while you're still
reading it is a weak idle signal), 1 minute anywhere else (menus, games, settings — browsing a list
untouched is a much stronger idle signal). Any input wakes the device (`wake()`), which redraws
the current screen and flashes once, consuming that same input as "just a wake" rather than also
acting on it. Long-press EXIT sleeps immediately, bypassing the timer.

## Book loading: local EPUB vs. built-in library

On boot, the simulator first tries `tryAutoLoadLocalEpub()` — a dev-server convenience that looks
for an EPUB file sitting next to `sim.html` (via a directory listing fetch) and auto-loads it if
found, landing straight in that book. This only works when actually serving the folder locally
(`python -m http.server`, per the README); the published Artifact/GitHub Pages deployment has no
filesystem to list, so it always falls through to `loadBuiltinLibrary()` instead — three genuinely
US-public-domain Project Gutenberg books (see the root README's Sources & inspirations section),
landing on the Library screen so there's something to look at immediately.

## Persistence

Independent `localStorage` keys, all scoped to the browser/origin they're used in (not shared with
real firmware, which would use small LittleFS records instead):

- `rotaryReaderLibrary_v1` — per-book resume position and bookmarks, keyed by `title::author`
  (not the book file itself — re-loading the *same* EPUB, or the built-in samples, restores where
  you left off; a different EPUB with the same title/author would collide, and a differently-titled
  copy of the same book wouldn't be recognized as the same book).
- `rotaryReaderReadingLog_v1` — per-book daily `{pages, seconds}` buckets backing
  [Reading stats](#reading-stats), also keyed by `title::author` and pruned to the most recent 120
  days per book.
- `rotaryReaderRulerScale_v1` — the true-size calibration slider's last value.
- `rotaryReaderTrueSizeDisplay_v1` — whether the "also resize the simulator's actual display"
  checkbox is on (see [True-size calibration](#true-size-calibration)).

All of them fail silently (try/catch) in private browsing or when storage is disabled — resume
position, bookmarks, reading stats, and calibration just won't persist in that case, rather than
the app erroring out.

## Deliberately not simulated: battery percentage

The stock CrowPanel schematic has no battery-voltage sense line at all — the MCU has zero
visibility into battery state as shipped, so there's nothing honest to display. The simulator
therefore shows no battery indicator anywhere (not on the sleep screen, not on boot). Firmware
mirrors this: `battery::readPercent()` returns `-1` while `PIN_BATTERY_ADC` is unset (the
default), and `main.cpp` only appends a percentage to the boot status line when the reading is
non-negative. Adding two SMD resistors as a divider and setting `PIN_BATTERY_ADC` in
`firmware/src/config.h` is what makes a real percentage available — see `battery.cpp`.

## Deliberately not simulated: portrait mode

The panel is a 122×250 sensor that's physically portrait-native, but that's roughly 19
characters per line — bad enough that portrait was never worth shipping as a real option. The
simulator renders unconditionally rotated (250×122 landscape), matching a hardcoded
`display.setRotation(1)` in `firmware/src/renderer.cpp`. There is no orientation toggle anywhere
in the UI; this is a deliberate simplification, not an oversight or an unfinished feature.

## The site around the simulator

`sim.html` is one page of four, all deployed together from `simulator/`:

| Page | What it's for |
|---|---|
| `index.html` | The landing page — what the project is, its features, how you'd set one up. Content only, no simulator. |
| `sim.html` | This document's subject: the device simulator. |
| `install.html` | A Web Serial installer that flashes a connected ESP32-S3 straight from the browser, using binaries the Pages workflow builds. |
| `docs.html` | Renders every doc in `docs/` (see [Docs page](#docs-page)). |

The three content pages share `site.css` and `theme.js` (a light/dark toggle that defaults to the
OS setting and remembers an explicit choice). `sim.html` deliberately shares nothing: it's also
published standalone as a Claude Artifact, which is a single self-contained file with no siblings
to link to, so everything it needs has to be inside it.

## The sidebar, and what isn't in it

The sidebar is deliberately limited to things that act on the simulated device: loading a
book, the memory readout, the library, wallpapers, and the layout parameters. Everything
below that — the AI-assistance disclosure, sources and inspirations, the list of hardware
divergences — used to be panels on this page and now lives on the [docs page](#docs-page)
instead. The reading UI is supposed to preview what the device feels like; a wall of project
prose underneath it was working against that, and none of it has an on-device counterpart.

What stays on `sim.html` is a one-line disclosure with links into the docs, so the
"vibe coded" statement is never more than a sentence away from the thing it's about — that
matters most in the published Artifact, which is a single file with no docs page next to it.
Those links (`[data-site-link]`) are relative by default and get repointed at the deployed
site by `resolveSiteLinks()` if `docs.html` turns out not to be reachable, which is exactly
the Artifact case.

## Docs page

`simulator/docs.html` is a standalone page — reached from `sim.html`'s footer links, never
embedded inside it — that renders the full text of every doc in `docs/`, in-site, with a
grouped left-hand index to switch between them. Hash-routed (`#about`, `#divergences`,
`#firmware-review`, `#architecture`, `#format`, `#flash-budget`, `#simulator`), so a link to a
specific doc is shareable. It exists only because this simulator does, and is deliberately
kept out of the main page:

- **It's a design/dev-reference tool, not part of the on-device experience.** The reading UI
  (`sim.html`'s canvas + sidebar) is meant to preview what the actual reader will feel like;
  a documentation browser doesn't belong inside that illusion.
- **The real device doesn't get any of this.** `firmware/data/index.html` — the small loader page
  the ESP32's own `web_server.cpp` actually serves for uploading books — is a separate, much
  simpler file with nothing docs-related anywhere near it. Keeping the docs browser as its own
  file in `simulator/` means "does this belong on the device's page" never has to be asked.

Content is fetched at page load (`fetch('docs/' + file)`) and rendered by a small hand-rolled
markdown-to-HTML converter (`renderMarkdown` in `docs.html`) — headings (with slug `id`s for
anchor links), paragraphs and list items with lazy line-wrap continuation, fenced code blocks, and
GFM-style pipe tables; checked against exactly what these docs actually use, not a general
CommonMark implementation. Same reasoning as the hand-rolled ZIP reader in `sim.html`: no bundled
library, so it behaves identically wherever it's served from. If a doc fails to load (`docs/` not
reachable next to `docs.html` — a bare `file://` open, or a server started somewhere that doesn't
include it), that one doc's pane shows an inline error with a "Read it on GitHub instead" link
rather than the whole page breaking.

`docs.html` isn't part of the Claude Artifact published from `sim.html` (only that one
self-contained file is ever published as an Artifact) — it only exists as a real page in the repo
and the GitHub Pages deploy.

## What's simulator-only (nothing to port to firmware)

A few systems exist purely because a browser stands in for hardware that isn't in hand yet, and
have no real-firmware equivalent to write — see
[docs/FLASH_BUDGET.md](FLASH_BUDGET.md#what-doesnt-need-to-be-ported-at-all) for the full
reasoning:

- Ghosting/flash-sequence simulation (a real panel ghosts physically; firmware just calls
  GxEPD2's partial/full refresh).
- Fullscreen API, rotate prompt, haptics — stand-ins for not holding the physical device.
- `localStorage` for resume/bookmarks/stats — the *behavior* is ported; the storage backend isn't
  the same thing. Firmware keeps the equivalent record in `/state.json` on LittleFS
  (`firmware/src/library.cpp`).
- Local-EPUB auto-load via directory listing — a dev-server convenience; firmware just lists
  whatever's already in `/books`.
- The layout-parameter sliders — a design-time tool for choosing the constants to compile into
  `firmware/src/config.h`, not a setting the device can offer (see
  [Hardware divergences](HARDWARE_DIVERGENCES.md)).

Everything else in this document *is* now on the device: the screen stack, the two-layer menu, all
six gestures, library/chapters/bookmarks/stats, the five games, idle sleep with a wallpaper, and
resume position. [Firmware review](FIRMWARE_REVIEW.md) has the feature-by-feature table.

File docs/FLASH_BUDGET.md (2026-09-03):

# Flash & RAM budget

Answering two questions directly: **will everything built in the simulator actually run
on the ESP32-S3**, and **how much flash is left for books once firmware, wallpapers,
and the filesystem itself are accounted for**.

## RAM: not the constraint

ESP32-S3 has 512KB of internal SRAM plus the 8MB of external PSRAM this board wires up
(per Elecrow's spec sheet). Everything built in the simulator this session — the
menu/screen-stack system, five games (Lights Out, Minesweeper, Sudoku, Tic-Tac-Toe,
Hangman), library/bookmarks/resume state, a dithered Voronoi background, ghosting
simulation — measures in the tens of KB at most:

- Largest game state (Sudoku: an 81-cell grid + a given-mask, both tiny arrays) is
  under 1KB.
- Tic-Tac-Toe's minimax explores at most 9! nodes, in practice far fewer — sub-
  millisecond on a 240MHz core, let alone what it'd be in native C++ vs. the browser's
  JS engine.
- The Sudoku generator's backtracking fill is the heaviest single computation here, and
  it's still a one-shot 81-cell search — negligible.
- The actual e-ink framebuffer (GxEPD2, native 122×250 1-bit) is ~3.8KB. Even holding
  two (for partial-refresh double-buffering) is nothing against 512KB, let alone 8MB of
  PSRAM.

None of this requires PSRAM at all — internal SRAM alone covers it with enormous
headroom. **RAM was never the risk on this board; flash is, because there's no SD slot.**

Since confirmed by a real build: the full firmware — menus, all five games, the library
model, reading stats — reports **60,176 bytes of static RAM, 18% of internal SRAM**, with
267,504 bytes left for stack and heap (see the measured figures below).

## What doesn't need to be ported at all

Several things built for the simulator exist *because* it's a browser standing in for
hardware, not because real firmware needs an equivalent:

- **Ghosting/multi-flash simulation** (`commitFrame`, `applyGhosting`, `flashSequence`)
  — a canvas can't physically ghost, so the simulator fakes it. Real firmware just
  calls GxEPD2's partial/full refresh and the *physical panel* ghosts on its own. This
  is pure simulator scaffolding with zero firmware counterpart to write.
- **Fullscreen API, touch swipe, haptics (Vibration API), the rotate-to-landscape
  prompt** — all stand-ins for not having the physical device in hand yet. The real
  board has no touchscreen, no vibration motor, and is always "fullscreen" (it's a
  dedicated display, not a browser tab).
- **`localStorage` for bookmarks/resume position** — firmware equivalent is a small
  file per book in LittleFS (or NVS/Preferences for something this small), not a
  behavior that needs porting so much as a storage backend that needs picking.
- **Local-EPUB auto-load via directory listing** — a dev-server convenience; real
  firmware just lists whatever's already in `/books`.

What's left after subtracting all of that — the menu/input state machine, the games'
logic, the library data model — is ordinary C++ business logic. None of it is CPU- or
RAM-heavy enough to be a real porting risk.

## Flash: the actual constraint, and a concrete partition table

The earlier `platformio.ini` referenced `default_8MB.csv` on the assumption that
PlatformIO's espressif32 platform ships something reasonable — that was never actually
verified, so it wasn't a fact this doc could build on. `firmware/partitions.csv` now
defines the layout explicitly instead:

| Partition  | Offset | Size | Notes |
|---|---|---|---|
| (bootloader + partition table) | `0x0000` | 36,864 B (36KB) | Fixed ESP32 region before any partition |
| `nvs` | `0x9000`  | 24,576 B (24KB) | WiFi credentials (WiFiManager), Preferences |
| `phy_init` | `0xF000`  | 4,096 B (4KB) | RF calibration data |
| `factory`  | `0x10000` | 2,097,152 B (2.00 MiB) | The firmware binary — see estimate below |
| `littlefs` | `0x210000`| 6,225,920 B (5.94 MiB) | Books + wallpapers |

Verified this sums to exactly 8MB (`0x210000 + 0x5F0000 = 0x800000`), not by inspection
but by adding it up in `node` and checking — see the arithmetic isn't just eyeballed.
No `otadata`/dual-app partitions: there's no OTA-over-WiFi flow implemented, so that
space goes to LittleFS instead, which matters more on a board with no SD slot.

### The 2MB app partition: now measured, not estimated

This has since been **compiled for real** — `arduino-cli` with `esp32:esp32` core 3.3.10,
targeting `esp32:esp32:esp32s3`, against the same libraries `platformio.ini` pins. The
size report:

| Measure | Bytes | Against |
|---|---|---|
| Firmware binary | **1,356,955 B** (1.29 MiB) | 65% of the 2 MiB `factory` partition — **~740 KB headroom** |
| Static RAM (globals) | **60,176 B** (58.8 KiB) | 18% of internal SRAM, leaving 267,504 B for the stack/heap |

The earlier estimate below predicted ~1.2–1.5MB. The real number landed inside that range,
so the 2MB partition stands as-is — no `partitions.csv` change needed.

<details>
<summary>The original estimate, kept for reference</summary>

| Component | Typical contribution |
|---|---|
| Base Arduino-ESP32 sketch (no WiFi) | ~250–300KB |
| + WiFi/LWIP/mbedTLS (needed by WiFiManager, AsyncWebServer) | +~400–550KB |
| + ESPAsyncWebServer + AsyncTCP | +~50–150KB |
| + WiFiManager (captive portal, its own mini web server) | +~150–300KB |
| + GxEPD2 + U8g2_for_Adafruit_GFX (only the ~5 fonts actually referenced get linked, not the whole font library) | +~40–70KB |
| + ArduinoJson, our own application code | +~30–50KB |
| **Estimated total** | **~1.2–1.5MB** |

</details>

Two caveats on the measurement. It's an `arduino-cli` build, not `pio run` — PlatformIO
pins its own core version, so the exact byte count will shift a little. And the 58.8 KiB
static-RAM figure counts only globals; it doesn't include what LittleFS, WiFi and the
async web server allocate on the heap at runtime. Both are close enough to settle the
partition question, which is what this section exists for.

### The table above is what actually gets flashed

Worth confirming rather than assuming, because it's the kind of thing that fails silently:
the CI build (`.github/workflows/pages.yml`) drops `partitions.csv` into the sketch folder
and selects `PartitionScheme=custom`, and a stock Arduino table would have been substituted
without complaint if that didn't take. Parsing the `partitions.bin` the workflow publishes
gives:

| Label | Type | Offset | Size |
|---|---|---|---|
| `nvs` | data | `0x9000` | 24,576 B |
| `phy_init` | data | `0xf000` | 4,096 B |
| `factory` | app | `0x10000` | 2,097,152 B |
| `littlefs` | data | `0x210000` | 6,225,920 B |

Byte-for-byte what `firmware/partitions.csv` specifies — so the ~5.94 MiB of book storage
this document's arithmetic depends on is what a flashed board will really have.

## Wallpapers: cheap, by design

A wallpaper is stored as a raw 1-bit bitmap at the panel's native 122×250 resolution —
**not** the source photo. That's `122 × 250 / 8 = 3,813 bytes` (~3.7KB) per wallpaper,
regardless of how large or colorful the original image was, because the dithering that
turns it into that bitmap happens once, client-side, in the browser (or the web panel
upload flow), the same way EPUB conversion already offloads the expensive one-time work
off the device — see `docs/ARCHITECTURE.md`. Even a generous 20 wallpapers is ~76KB —
noise against a multi-MB budget. This is the reason the simulator never embeds a
wallpaper's *source* file into anything meant to represent firmware storage; only the
tiny dithered bitmap corresponds to what real flash usage looks like.

## Books: how many actually fit

Using the three built-in sample books (real EPUBs run through the actual conversion
pipeline, not placeholder text) as a size reference:

| Book | Extracted text | Estimated `.cebk` size |
|---|---|---|
| Alice's Adventures in Wonderland | 162KB | ~186KB |
| The Strange Case of Dr. Jekyll and Mr. Hyde | 157KB | ~180KB |
| The Wonderful Wizard of Oz | 226KB | ~259KB |
| **Average** | | **~208KB** |

(`.cebk` size = text bytes + structural overhead from `docs/FORMAT.md`'s line/page/run
tables — estimated at ~38 chars/line and ~9 lines/page for the landscape layout, and
~5% of lines carrying a bold/italic/heading run. Reasoned the same way as the app-size
estimate above: methodology stated, not measured from a real conversion run of these
exact books through `converter.js` — worth doing once there's reason to, but the order
of magnitude is what matters here.)

LittleFS itself has a small bookkeeping overhead (metadata blocks, wear-leveling
margin) — call it ~95% of the raw partition usable for actual file content, which is a
reasonable assumption for a filesystem holding a few dozen largeish files rather than
thousands of tiny ones:

```
5.94 MiB partition × 0.95 ≈ 5.64 MiB usable
5.64 MiB / ~208KB average book ≈ ~27–28 books this length
```

**That's the headline number: roughly two to three dozen novella-length books, fewer if
they run longer** (a full unabridged doorstop like *Moby-Dick* or *War and Peace* could
be 1–1.5MB+ on its own), more if they're shorter. A handful of wallpapers barely moves
this number at all — books are the entire story here, exactly because there's no SD
card to fall back on.

## Bottom line

- **RAM/CPU: not a risk.** Everything simulated this session fits ESP32-S3 with room
  to spare, and several simulator-only systems (ghosting, fullscreen, haptics) don't
  even need porting.
- **Flash: the real constraint, now with a concrete number.** ~5.9MB for LittleFS,
  ~27 books at this length, wallpapers costing next to nothing. The one figure that
  still needs a real build to confirm is firmware binary size — everything downstream
  of that (this whole book-count estimate) shifts a little if it does, but not by an
  order of magnitude.

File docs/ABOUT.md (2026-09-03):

# About this project

A DIY e-reader built around the [Elecrow CrowPanel ESP32 2.13" E-Paper HMI
Display](https://www.elecrow.com/crowpanel-esp32-2-13-e-paper-hmi-display-with-122-250-resolution-black-white-color-driven-by-spi-interface.html)
— an ESP32-S3 with a 122×250 black-and-white e-paper panel, a rotary encoder and two
buttons, and no SD slot. EPUBs are converted in the browser to a precomputed binary format
(`docs/FORMAT.md`) and uploaded over WiFi, so the device itself does no text layout at all.

The browser simulator you're reading this from is the design tool for it: same pagination
logic, same input model, an approximation of e-ink refresh behavior.

## Disclosure: this is "vibe coded"

The firmware, converter, simulator, and these docs were written collaboratively with
[Claude](https://claude.com/claude-code) (Anthropic), directed and reviewed by a human,
**without physical access to the target hardware**. Nothing here has run on a real board.
Pin mappings, driver classes and refresh timing are reasoned from Elecrow's published
schematic and datasheets — treat them as needing a multimeter check, not as measured fact.
[Hardware divergences](HARDWARE_DIVERGENCES.md) lists what the simulator fakes and why.

## What the firmware review found

The firmware was reviewed end-to-end and built against a real toolchain (`arduino-cli`
with ESP32 core 3.3.10) rather than only read. That build is what turned several
"looks fine" judgements into facts — the headline one being that **the firmware did not
compile at all** before this pass.

Fixed:

- **A compile error in the display setup.** `renderer.cpp` called a `GxEPD2::init()`
  overload that doesn't exist (five arguments ending in a `SPIClass&`); the bus has to be
  selected separately via `epd2.selectSPI()`. Nothing downstream of this could ever have
  run.
- **Undefined behavior on a truncated or corrupt `.cebk`.** The 16- and 32-bit readers
  returned uninitialized stack bytes when a read came up short, which became wild file
  seeks and multi-megabyte `reserve()` calls. Reads are now checked, and the chapter
  table, page table and text-blob bounds are all validated.
- **A wake-from-sleep bug that would have looked like a dead device.** Light sleep armed
  `ext1` with `ALL_LOW` across all five inputs — meaning every button had to be held down
  simultaneously to wake it. It's `ANY_LOW` now.
- **Dropped button presses.** The input poll returned on the first pressed button, so the
  other buttons' debounce state machines didn't advance that tick. Every button is now
  polled every tick and events are queued.
- **Books that only appeared after a reboot** (the upload callback was an empty `TODO`),
  **a library scan that didn't filter for `.cebk`** or close its file handles, and a path
  construction that broke on ESP32 core versions where `File::name()` returns a full path.
- **The panel never being put to sleep.** `Renderer::powerDown()` existed and was never
  called, so the display rail stayed powered indefinitely.
- **Reading position lost on every reboot** — there was no persistence of any kind.
- **Per-span file I/O inside the draw loop.** Rendering a page did a seek, a heap
  allocation and a `String` construction *per styled span*; it now reads the page's text
  once into a reusable buffer. The style-run scan is no longer O(spans × runs) either.
- **A converter crash on non-ASCII titles.** Titles were truncated by character count but
  length-prefixed by byte count, so a long title in any non-Latin script threw instead of
  being truncated.

The full list, including what was checked and found correct, is in
[Firmware review](FIRMWARE_REVIEW.md).

## Firmware/simulator parity

The firmware used to be a reading skeleton: open the first book found, turn pages, and
nothing else — MENU and EXIT were explicitly unimplemented. The menu system, games,
bookmarks and stats existed only in this simulator.

That gap is closed. The device now has the same screen stack, the same two-layer menu
(MENU opens the current book's menu, EXIT opens Home), the same six gestures, the same
five games, bookmarks, reading stats, idle sleep with a wallpaper, and resume-where-you-
left-off. [Simulator UI/UX](SIMULATOR.md) documents the intended behavior for both.

Two deliberate differences remain, both of them honest ones:

- **Layout parameters aren't adjustable on the device.** Margin, line height and font size
  are baked into every `.cebk` at conversion time, so the on-device Settings screen shows
  them as fixed values instead of offering sliders that would desync the page tables.
- **No battery indicator.** The stock schematic has no battery-sense line at all, so
  `battery::readPercent()` returns `-1` and nothing displays a percentage. Two SMD
  resistors and one `config.h` constant would change that.

## Sources & inspirations

- **Hardware.** [Elecrow CrowPanel ESP32 2.13" E-Paper HMI
  Display](https://www.elecrow.com/crowpanel-esp32-2-13-e-paper-hmi-display-with-122-250-resolution-black-white-color-driven-by-spi-interface.html).
- **Precedent projects** (see [Architecture](ARCHITECTURE.md) for how this one differs):
  [atomic14/diy-esp32-epub-reader](https://github.com/atomic14/diy-esp32-epub-reader)
  (equivalent tag-stripping, done on-device) and Soldered's Inkplate 6FLICK (host-side
  Python EPUB pre-conversion). This project follows the second pattern, in the browser,
  with pagination also moved off-device.
- **Firmware libraries.** GxEPD2, U8g2_for_Adafruit_GFX, Adafruit GFX Library,
  WiFiManager, ESPAsyncWebServer/AsyncTCP, ArduinoJson.
- **Converter.** JSZip, for standalone EPUB unzipping outside this simulator.
- **Fonts.** Silkscreen, IBM Plex Mono and IBM Plex Sans (Google Fonts).
- **Sample books.** *Alice's Adventures in Wonderland*, *The Strange Case of Dr. Jekyll and
  Mr. Hyde*, and *The Wonderful Wizard of Oz* — genuinely US-public-domain texts via
  [Project Gutenberg](https://www.gutenberg.org/).

Full source, issues and the README:
[github.com/trimpta/esp32-epaper-ereader](https://github.com/trimpta/esp32-epaper-ereader).

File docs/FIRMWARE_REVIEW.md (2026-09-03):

# Firmware review

A full read-through of `firmware/src/`, checked against a real toolchain rather than by
inspection alone, plus a parity pass against what the simulator actually does.

## How it was verified

There's still no physical board. What changed is that the firmware is now **compiled**:
`arduino-cli` with `esp32:esp32` core 3.3.10, targeting `esp32:esp32:esp32s3`, against the
same libraries `platformio.ini` pins (GxEPD2, U8g2_for_Adafruit_GFX, Adafruit GFX,
WiFiManager, an ESPAsyncWebServer/AsyncTCP pair, ArduinoJson).

That distinction matters: the single most serious bug below is one no amount of careful
reading had caught, and one that a build catches immediately.

What a compile still can't tell you: whether `GxEPD2_213_BN` is the right driver class for
this panel, whether the SPI/EPD pin numbers read off the schematic are correct, whether the
`ext1` wake pin set is valid on this board, or what a refresh actually looks like. Those
remain hardware-verification items — see the README's status section.

## Bugs found and fixed

### 1. The firmware did not compile

`renderer.cpp` called `display.init(115200, true, 20, false, SPI)`. GxEPD2 has no `init()`
overload taking a bare `SPIClass&` — the SPI bus is selected separately:

```cpp
SPI.begin(PIN_EPD_SCK, -1, PIN_EPD_MOSI, PIN_EPD_CS);
display.epd2.selectSPI(SPI, SPISettings(4000000, MSBFIRST, SPI_MODE0));
display.init(115200, true, 20, false);
```

Everything else in this document is downstream of a binary that could never have been built.

### 2. Undefined behavior on a corrupt or truncated `.cebk`

`readU16()`/`readU32()` declared a local byte array, passed it to `File::read()`, and
returned it **without checking how many bytes were actually read**. At EOF that's whatever
was on the stack. Those values are file offsets and element counts, so a truncated book
produced arbitrary seeks and `reserve()` calls sized by garbage.

Three related holes, all now closed:

- `chapters_.reserve(chapterCount)` trusted a `uint16_t` from the header — up to 65,535
  entries — with no sanity check against the file's actual size.
- `getPageLines()` computed `endLine - startLine` in unsigned arithmetic and passed it to
  `reserve()`. A page table where `endLine < startLine` asked for a multi-gigabyte
  allocation.
- `readText()` never bounds-checked against the text blob, even though the blob's length is
  right there in the header (it was read and discarded). Past the end, it rendered whatever
  bytes followed in the file.

The reader now zero-fills, tracks short reads in a `readOk_` flag, validates every table
offset against the file size, and refuses to open a book that fails those checks.

### 3. Light sleep could only be woken by pressing every button at once

`esp_sleep_enable_ext1_wakeup(mask, ESP_EXT1_WAKEUP_ALL_LOW)` with all five inputs in the
mask means "wake when **all** of these are low simultaneously." The buttons are active-low
and independent, so the intent was clearly any-of-them. On a board where this path was
enabled, that reads as a device that goes to sleep and never comes back.

Now `ESP_EXT1_WAKEUP_ANY_LOW`, with each pin checked via
`esp_sleep_is_valid_wakeup_gpio()` first and a `false` return so the caller can fall back to
polling rather than sleeping forever.

### 4. Dropped button presses

`input::poll()` returned as soon as it found one pressed button, so the remaining buttons'
debounce state machines didn't advance on that tick. Every button is now polled every tick,
with events queued in a small ring buffer.

### 5. Only three of the six gestures existed

The simulator's input model is short *and* long press on MENU, EXIT and the rotary's click.
Firmware had no long-press detection at all, which meant no force-full-refresh, no
sleep-now, and no scrub-to-edit. All six now exist, at the same 550 ms threshold the
simulator uses.

### 6. Library handling

`openFirstBook()` opened whatever `openNextFile()` returned first: no `.cebk` filter (a
half-finished upload would be picked instead of a book), no directory check, no `close()`,
and `String(BOOKS_DIR) + "/" + f.name()` — which produces `/books//books/x.cebk` on ESP32
core versions where `File::name()` returns a full path. Replaced by `library.cpp`, which
scans properly, reads each book's header for title/author/page count, and skips anything
that fails to parse.

### 7. The panel was never put to sleep

`Renderer::powerDown()` (a `display.hibernate()` wrapper) existed and was never called, and
`PIN_EPD_POWER_CTL` was driven high at boot and left there. The display now hibernates when
the reader goes to sleep.

### 8. No persistence

Nothing was saved. Every reboot reopened the first book at page one. The device now keeps
resume position, bookmarks and reading stats in `/state.json`, written debounced (on sleep,
and at most once per 30s of quiet) rather than on every page turn, and via a
write-temp-then-rename so a power cut mid-write can't destroy the whole library's state.

### 9. Uploads needed a reboot

`web_server::begin()`'s "a book finished uploading" callback was an empty `TODO`. It now
triggers a library rescan.

### 10. Converter: non-ASCII titles threw

`converter.js` truncated titles with `slice(0, 255)` — 255 **characters** — then
length-prefixed them with a byte count that must fit in a `uint8_t`. Any title long enough
in a non-Latin script exceeded 255 bytes and threw, aborting the conversion. Chapter titles
weren't truncated at all. Both now truncate on a UTF-8 byte boundary.

## Efficiency

- **Page rendering did file I/O per styled span.** Each span meant a `seek()`, a
  `std::vector` allocation and a `String` construction, inside the draw loop — dozens of
  small reads per page turn. A page's text is now read once into a reusable static buffer
  and printed straight from it.
- **Style-run lookup was O(spans × runs).** Every span rescanned the chapter's entire run
  table. Runs are sorted, and lines are drawn in order, so a monotonic cursor now carries
  the scan position forward.
- **`loop()` still polls at 20 ms.** The idle-sleep path now hibernates the panel and stops
  drawing, but the CPU-side light-sleep handoff stays behind the unverified-`ext1` TODO —
  turning it on before the wake pins are confirmed is exactly the "sleeps and never wakes"
  failure mode above.

## Checked and found correct

Worth recording, so the next pass doesn't re-derive it:

- **The `.cebk` reader matches the writer**, field for field: magic, version, u8-length
  title/author, `u16` chapter count, then per chapter title / `u32` text offset / `u32`
  text length / `u16` line count + 6-byte line entries / `u16` page count + `u16` page
  starts / `u16` run count + 7-byte runs, then `u32` blob length and the blob.
  `converter.js`'s writer and `book_format.cpp`'s reader agree exactly, and both match
  [FORMAT.md](FORMAT.md).
- **The renderer's line-advance model matches the simulator's**, including the detail that
  both place the first baseline at `margin + LINE_HEIGHT` even when the first line is a
  heading. That's one pixel-row tighter than the paginator's box model assumes for a page
  that opens on a heading — it can only ever draw *less* tall than budgeted, so it can't
  overflow a page, and firmware and simulator are consistent with each other, which is what
  matters for previewing.
- **The layout constants agree across all three sides.** `converter/converter.js`'s `LAYOUT`
  and `firmware/src/config.h` both say 250×122, margin 4, line height 11, heading height
  14 — which they must, since the converter bakes page breaks computed from those numbers
  into each `.cebk` and the firmware draws with them.
- **The font table agrees between firmware and the metrics tool.**
  `renderer.cpp`'s `fontForFlags()` and `tools/dump_font_metrics` both use `helvR08`
  (regular *and* italic, which has no face at this size), `helvB08` (bold), `helvB12` (h1)
  and `helvB10` (h2). If those drifted, the converter would paginate against widths the
  panel never draws.
- **`battery::readPercent()` is correctly gated.** It returns `-1` while `PIN_BATTERY_ADC`
  is `-1`, and `main.cpp` only appends a percentage when the reading is non-negative — so
  the "no battery indicator" decision holds on both sides.
- **The WiFi reconnect backoff** doubles to a 60s ceiling and never re-enters the captive
  portal on its own, which is the right behavior for a phone hotspot that sleeps.

## Parity with the simulator

Before this pass, `main.cpp` said it plainly: *"Reserved for book list / TOC / settings
screens — not implemented in this skeleton."* MENU and EXIT did nothing. The device could
open the first book it found and turn pages; everything else — the menu system, library,
bookmarks, stats, games, sleep screen — existed only in the browser.

Now on device, matching [SIMULATOR.md](SIMULATOR.md):

| Feature | Simulator | Firmware |
|---|---|---|
| Screen stack + two-layer menu (MENU → book menu, EXIT → Home) | yes | yes |
| Six gestures (short/long on MENU, EXIT, rotary click) | yes | yes |
| Library / book menu / chapters / bookmarks | yes | yes |
| Reading stats (pages today, pages/day, est. finish, time read) | yes | yes |
| Settings | layout sliders (design-time) | runtime-safe values only |
| Wi-Fi screen incl. re-entering AP setup | yes | yes |
| Games (Lights Out, Minesweeper, Sudoku, Hangman, Tic-Tac-Toe) | yes | yes |
| Idle sleep + wallpaper sleep screen | yes | yes |
| Resume position, bookmarks persisted | localStorage | `/state.json` |
| Ghosting simulation, fullscreen, touch, haptics | yes | not applicable |

The remaining differences are deliberate and documented in
[Hardware divergences](HARDWARE_DIVERGENCES.md): layout parameters are compile-time on the
device, there's no battery indicator on either side, and the game cursor highlight is
computed rather than composited.

## Still unverified

Everything that needs the physical board, unchanged by this pass:

- `GxEPD2_213_BN` as the driver class for this panel's SSD1680Z/JD79661 controller.
- The EPD SPI pin map and the `IO7_LCD_3.3_CTL` rail-gating pin.
- Whether the `ext1` wake pin set is valid, which gates real power saving.
- Real refresh timing and ghosting behavior.
- Actual font metrics (`tools/dump_font_metrics`), which decide whether the converter's
  line breaks land where the panel draws them.
- Firmware binary size against the 2 MB app partition ([FLASH_BUDGET.md](FLASH_BUDGET.md)).

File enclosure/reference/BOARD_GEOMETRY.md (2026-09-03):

# CrowPanel 2.13" board geometry — measured, not guessed

Every number here was extracted from Elecrow's own CAD assembly
(`3D file/00-2-13_view_asm.rar` in
[Elecrow-RD/CrowPanel-ESP32-2.13-E-paper-HMI-Display-with-122-250](https://github.com/Elecrow-RD/CrowPanel-ESP32-2.13-E-paper-HMI-Display-with-122-250)),
opened in FreeCAD and queried per-part. This supersedes every placeholder dimension the
enclosure previously used.

## Reproducing this

```python
# freecadcmd extract.py  —  the Import module, NOT Part.insert (loses part labels)
# and NOT ImportGui (won't load headless).
import FreeCAD, Import
doc = FreeCAD.newDocument("probe")
Import.insert(r"...\00-2-13_view_asm.stp", "probe")
doc.recompute()
for obj in doc.Objects:
    if hasattr(obj, "Shape") and not obj.Shape.isNull():
        print(obj.Label, obj.Shape.BoundBox)
```

The full dump of all 519 objects is in `step_parts_dump.json` next to this file.

## Coordinate system

The assembly is in the board's **native portrait** frame, in millimetres:

| Axis | Span | Meaning |
|---|---|---|
| **X** | −15.60 … +15.60 (31.20 mm) | Board width — matches the published 31.2 mm display "H" |
| **Y** | −2.10 … 0.00 (2.10 mm) | Board thickness. **0 is the display face; −Y is the component side** |
| **Z** | −31.60 … +31.60 (63.20 mm) | Board length — matches the published 63.19 mm display "L" |

### Mapping to what you see

Viewed **from behind** (looking at the component side, the way Elecrow's product photo shows
the PCB), confirmed against both the photo and the owner's direct description:

- **Z<sub>min</sub> (−31.6) is the LEFT edge**, Z<sub>max</sub> (+31.6) is the RIGHT edge
- **X<sub>min</sub> (−15.6) is the TOP edge**, X<sub>max</sub> (+15.6) is the BOTTOM edge

This holds together on every part below: the buttons land on the left, USB-C lands centred
on the bottom, BOOT/RESET land top-right. Note the reader is used in **landscape** (the
firmware does `setRotation(1)`), so the board's long Z axis is horizontal in use.

## Parts

Bounding boxes are global, in the frame above.

| Part | STEP label | X | Y | Z |
|---|---|---|---|---|
| PCB | `2_13_PCB` | −15.60 … 15.60 | −2.10 … 0.00 | −31.60 … 31.60 |
| Display module | `2_13-LCD` | −14.60 … 14.60 | −2.084 … 0.90 | −29.60 … 30.448 |
| **MENU** | `KEY-579_ASM` | −15.00 … −7.30 | −5.10 … −1.60 | −32.40 … −28.90 |
| **Rotary encoder** | `XB-TM-2024A` | −6.582 … 6.582 | −3.80 … −1.00 | −34.349 … −25.35 |
| **EXIT** | `KEY-579_ASM001` | 7.30 … 15.00 | −5.10 … −1.60 | −32.40 … −28.90 |
| **BOOT** | `TACT_SWITCH_ASM_2_1_ASM` | −14.175 … −9.625 | −8.10 … −1.584 | 11.45 … 18.95 |
| **RESET** | `TACT_SWITCH_ASM_2_1_ASM001` | −14.175 … −9.625 | −8.10 … −1.584 | 21.92 … 29.42 |
| **USB-C** | `TYPE_C_PORT_SMD_TYPE__ASM_2_1_ASM` | 7.70 … 15.60 | −4.81 … −0.61 | −3.87 … 5.07 |

## What the numbers mean for cutouts

**MENU, Rotary and EXIT are edge-mounted on the left (Z<sub>min</sub>) edge and actuate along
−Z.** All three extend *past* the PCB outline at that edge — the rotary by 2.75 mm
(Z −34.349 vs. the board's −31.60), MENU and EXIT by 0.8 mm each. That protrusion is the
part that has to come through the case wall, and it's the reason these want a wall opening
rather than a face hole.

Across the left edge, top to bottom: **MENU** (centre X ≈ −11.15), **Rotary** (centre X = 0),
**EXIT** (centre X ≈ +11.15).

**BOOT and RESET are not on any edge.** They sit 1.4 mm inboard of the top edge and protrude
6 mm out the **component face** (−Y), so they're pressed from behind the board, not from a
side. Centres: BOOT at Z ≈ 15.2, RESET at Z ≈ 25.67, both at X ≈ −11.9. Pinholes through
whatever panel covers the component side, not wall cutouts.

**USB-C sits flush with the bottom (X<sub>max</sub>) edge**, centred lengthwise (Z ≈ 0.6),
spanning Z −3.87 … 5.07 (≈ 8.9 mm wide) and 4.2 mm deep in Y. Unlike the buttons it doesn't
overhang the board outline, so the wall opening needs to clear the *plug*, not the socket.

**The rotary needs rotational clearance, not just a hole** — and it is a flat in-plane
**thumbwheel**, not a shaft with a knob. Its X span *is* its full diameter (a circle
reaches its X extremes at its centre's Z), so:

| | |
|---|---|
| diameter | 13.164 mm (radius 6.582) |
| centre | X = 0, Z = **−27.767** (= −34.349 + 6.582) |
| thickness | 2.80 mm (Y −3.80 … −1.00) |

The STEP solid is only about a 223° arc of that circle, which is why its Z span (9.0 mm)
is smaller than its diameter — the wheel is a C shape open towards the board interior.
The product photo shows exactly that: a toothed wheel of about that size, its rim poking
out of the left edge. A wall opening must clear the swept circle, which at 0.4 mm outside
the board edge is 2 × 5.04 = 10.08 mm across.

## Independent cross-check against the product photo

Every position above was re-measured by pixel analysis of
`docs/images/hardware-overview.webp`, using the detected board outline as the scale
reference (13.85 px/mm). Independent of the STEP file:

| Feature | Photo | STEP | Delta |
|---|---|---|---|
| MENU centre, board X | −11.16 | −11.150 | 0.01 |
| EXIT centre, board X | +11.16 | +11.150 | 0.01 |
| Rotary width, board X | 13.29 | 13.164 | 0.13 |
| Rotary protrusion past the edge | 2.1–2.7 | 2.749 | – |
| MENU/EXIT protrusion past the edge | 0.83 | 0.80 | 0.03 |
| BOOT centre, board Z | +15.23 | +15.200 | 0.03 |
| RESET centre, board Z | +25.60 | +25.670 | 0.07 |
| USB-C centre, board Z | +0.40 | +0.600 | 0.20 |
| BOOT/RESET cap centre, board X | −12.24 / −12.28 | −11.900 | 0.35 |

The last row is the only one over 0.2 mm, and it compares the visible cap against the
whole switch assembly's bbox centre, partly occluded by the photo's annotation dot. The
enclosure's pinholes are oversized (Ø1.8) to absorb it.

## Mounting holes — there are none. CORRECTED.

> **Correction, made while building the enclosure.** An earlier revision of this file
> read the PCB solid's cylindrical faces as mounting holes. They are not holes. The
> board has **no mounting holes at all**. What follows is the corrected reading.

Walking the PCB solid's cylindrical faces (they're cut features in the board, not
separate parts, so they don't appear in the parts dump) turns up six, and only six:

| Count | Radius | Positions (X, Z) | What they actually are |
|---|---|---|---|
| 4 | 1.00 mm | centred (±14.60, ±30.60) | the **outline's corner fillets** |
| 2 | 0.50 mm | centred (±7.00, 30.30) | the rounded **ends of the FPC slot** |

Why they are not holes:

- A Ø2.00 hole whose centre sits exactly 1.00 mm from the edge is *tangent* to that edge —
  it would break out of the board. Not manufacturable. R1.00 centred 1.00 mm in from both
  edges, at all four corners, is instead the exact signature of a 1 mm corner round, and
  the product photo shows corners rounded at about that radius.
- Three of the four positions sit underneath a switch body. MENU spans X −15.000…−7.300
  at Z −32.400…−28.900, which contains (−14.60, −30.60); EXIT likewise contains
  (+14.60, −30.60). Nothing could be screwed there.
- The two R0.50 faces at (±7.00, 30.30) are 14.0 mm apart on one line — the two ends of a
  14.0 × 1.0 mm slot at Z = 30.30, 1.30 mm in from the right edge. That slot is plainly
  visible in the product photo at exactly that spot, with the display's FPC passing
  through it.
- Elecrow's wiki lists no mounting holes, and none are visible anywhere on the
  component-side photo.

Consequence for an enclosure: the board cannot be screwed down. It has to be clamped —
supported on a ledge around its perimeter and held by an opposing rib, both interrupted
where the components above reach the board edge.

## Still not measured

- Component *heights* above the component face beyond the bounding boxes above — enough for
  clearance, not enough to model a snug fit. In particular, how much of a back cavity a
  battery can really use is unknown until the board is in hand.
- The e-paper **active area's offset within the glass**. Its size is derivable
  (122 × 250 px at the panel's 0.1942 mm pitch = 23.71 × 48.55 mm) and the glass outline
  is (29.2 × 59.2, board Z −29.60 … +29.60 — the module bbox's extra 0.85 mm to +30.448
  is the FPC tail). Where the active rectangle sits inside that is not in the dump.
- Where the MENU/EXIT **actuator nub** sits within its switch's 7.7 mm-wide body. The
  photo puts the nub at about 2.9 mm tall and roughly centred, but the STEP solid is one
  lump.
- Whether the display's FPC bulges past the board's right-hand edge as it folds through
  the slot. The STEP says no; the photo is ambiguous.
- Anything about the acrylic shell Elecrow ships, which is in the same assembly but wasn't
  extracted here.

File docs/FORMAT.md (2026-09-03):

# .cebk binary format (v1)

"Custom E-Book". Everything is little-endian. Produced by `converter/converter.js`, consumed by
`firmware/src/book_format.h`. Both sides must agree on this file — bump the version byte on any
layout change.

Design goal: the device does **zero text layout**. Line-wrapping and page-breaking happen once,
in the browser, against real glyph-width data pulled from the device (see
`tools/dump_font_metrics`). The device just seeks to an offset and draws precomputed lines.

## Top-level layout

| Offset | Size | Field |
|---|---|---|
| 0 | 4 | Magic: ASCII `"CEBK"` |
| 4 | 1 | Format version (`1`) |
| 5 | 1 | `titleLen` (Lt) |
| 6 | Lt | `title`, UTF-8 |
| 6+Lt | 1 | `authorLen` (La) |
| ... | La | `author`, UTF-8 |
| ... | 2 | `chapterCount` (uint16) |
| ... | — | `chapterCount` × **chapter table entries** (variable length, see below) |
| ... | 4 | `textBlobLength` (uint32) |
| ... | textBlobLength | `textBlob` — UTF-8 text of every chapter, concatenated in order |

All offsets referenced from chapter/line/style-run entries below are **absolute byte offsets into
`textBlob`**, not relative to the chapter start — simpler to reason about on both sides, and the
cost (a few extra bytes per uint32) doesn't matter at this scale.

## Chapter table entry

| Size | Field |
|---|---|
| 1 | `titleLen` (Lc) |
| Lc | chapter `title`, UTF-8 |
| 4 | `textOffset` (uint32) — start of this chapter's text in `textBlob` |
| 4 | `textLength` (uint32) |
| 2 | `lineCount` (uint16) |
| lineCount × 6 | **line entries**: `{ offset: uint32, length: uint16 }` — one precomputed, already-wrapped line |
| 2 | `pageCount` (uint16) |
| pageCount × 2 | **page starts**: `uint16` index into this chapter's line array where each page begins |
| 2 | `styleRunCount` (uint16) |
| styleRunCount × 7 | **style runs**: `{ offset: uint32, length: uint16, flags: uint8 }` |

`flags` bitfield: `bit0` = bold, `bit1` = italic, `bit2` = heading-1, `bit3` = heading-2. Headings
imply bold at a larger font on-device; the converter never mixes heading with inline bold/italic
runs (a heading's whole line is one run).

## Rendering a page (device side, no measuring)

```
page = chapter.pageStarts[pageIndex]
nextPage = chapter.pageStarts[pageIndex + 1] or chapter.lineCount
cursor.y = TOP_MARGIN
for lineIdx in [page, nextPage):
    line = chapter.lines[lineIdx]
    cursor.x = LEFT_MARGIN
    for (spanOffset, spanLength, styleFlags) in splitByOverlappingStyleRuns(line, chapter.styleRuns):
        setFont(fontForStyle(styleFlags))       # regular/bold/italic/bold-italic/h1/h2
        u8g2.setCursor(cursor.x, cursor.y)
        u8g2.print(textBlob[spanOffset : spanOffset+spanLength])
        cursor.x = u8g2.getCursorX()             # u8g2 advances the cursor itself
    cursor.y += LINE_HEIGHT_PX
```

`splitByOverlappingStyleRuns` is a linear scan (style runs per line are almost always 0–2) — no
width computation on-device, u8g2's own cursor advance handles that.

## Layout constants the converter must paginate against

Defined once in `converter/converter.js` (`LAYOUT` object) and mirrored in
`firmware/src/config.h`. Keep them in sync manually — v1 doesn't embed them in the file.

- `PAGE_WIDTH_PX = 250`, `PAGE_HEIGHT_PX = 122` — landscape. The panel is natively
  122×250 portrait, but that's ~19 characters/line; firmware renders rotated
  (`display.setRotation(1)`, a draw-surface transpose, not a hardware change) for a
  reading-width line length. See `firmware/src/config.h` and `simulator/sim.html`.
- `MARGIN_PX = 4` on all sides
- `LINE_HEIGHT_PX = 11` (regular/bold/italic body text)
- `HEADING_LINE_HEIGHT_PX = 14`

## Why not store per-line style flags instead of a separate run table?

A run table is smaller (most chapters are almost entirely regular text — runs are the exception,
not the rule) and keeps the line table trivial to generate: the line-wrapper doesn't need to know
or care about styling, it just wraps a flat text+width stream. Styling is overlaid afterward by
intersecting line spans with the independently-tracked run list.

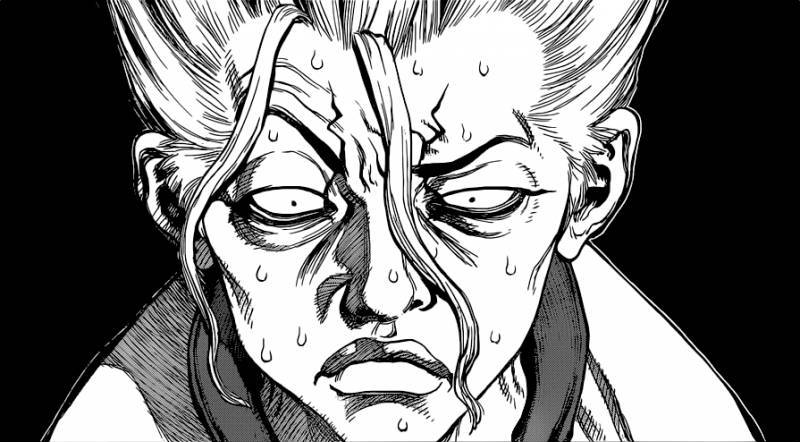
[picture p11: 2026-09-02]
assets/wallpapers/lighthouse.webp

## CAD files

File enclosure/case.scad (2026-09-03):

// ============================================================================
//  Parametric two-piece enclosure for the CrowPanel ESP32 2.13" E-Paper HMI
//  Display (Elecrow, 122x250, SPI).
// ============================================================================
//
//  WHERE THE NUMBERS COME FROM
//  ---------------------------
//  Every board dimension in this file is measured, not guessed. The source is
//  Elecrow's own CAD assembly (00-2-13_view_asm.stp, from
//  Elecrow-RD/CrowPanel-ESP32-2.13-E-paper-HMI-Display-with-122-250), opened in
//  FreeCAD and queried part-by-part. The extraction, the per-part bounding
//  boxes and the reproduction recipe live in enclosure/reference/ —
//  BOARD_GEOMETRY.md for the write-up, step_parts_dump.json for the raw dump of
//  all 519 solids.
//
//  Every one of those positions was then independently re-measured off the
//  annotated product photo (docs/images/hardware-overview.webp) by pixel
//  analysis, using the board outline as the scale reference. The two methods
//  agree to better than 0.4 mm on every control (see the cross-check table
//  below). Where they disagree, the STEP data wins.
//
//  The only numbers here that are NOT from the STEP file are:
//    * the e-paper active-area size (23.71 x 48.55 mm), which comes from the
//      122x250 pixel count at the panel's 0.1942 mm pitch, and
//    * generic hardware sizes (M2 screws, USB-C plug envelope, paperclip).
//  Both are flagged where they are used.
//
//  BOARD COORDINATE SYSTEM (the STEP assembly's own frame)
//  ------------------------------------------------------
//    board X : -15.60 .. +15.60   board width   (31.20 mm)
//    board Y :  -2.10 ..   0.00   board thickness; Y=0 is the DISPLAY face,
//                                 -Y is the COMPONENT side
//    board Z : -31.60 .. +31.60   board length  (63.20 mm)
//  Viewed from behind: Z-min is the LEFT edge, X-min is the TOP edge.
//
//  CASE COORDINATE SYSTEM used below (a cyclic, right-handed permutation, so
//  nothing is mirrored):
//    case x = board Z    (long axis; left wall at x-min)
//    case y = board X    (short axis; USB-C wall at y-max)
//    case z = PCB_FACE_Z + board Y   (0 = outside of the back shell's floor)
//  So a feature at board (X, Y, Z) is at case (Z, X, PCB_FACE_Z + Y).
//
//  WHAT LIVES ON WHICH FACE
//  ------------------------
//    LEFT wall  (x-min): MENU, rotary wheel, EXIT. All three are edge-mounted
//                        and actuate along -Z, and all three physically stick
//                        out past the PCB outline, so they need wall openings.
//    BOTTOM wall (y-max): USB-C, flush with the board edge, centred lengthwise.
//    BACK floor (z-min): BOOT and RESET pinholes. These two are NOT on an edge —
//                        they sit 1.425 mm inboard of the top edge and protrude
//                        6.0 mm out of the component face, so they are pressed
//                        from behind, through the floor.
//    FRONT frame:        screen aperture only.
//    TOP wall, RIGHT wall: nothing.
//
//  NO BUTTON EXTENDERS. There are deliberately no plungers, actuator pieces or
//  printed caps in this file. Direct cutouts only. The reach numbers are worked
//  out in the "ACTUATOR REACH" note further down.
//
//  ============================================================================
//  DERIVATION CHECK — cutout centre vs. the measured part it comes from
//  ============================================================================
//  Every opening centre below is the arithmetic midpoint of the measured
//  bounding box, converted into case coordinates. Checked before modelling:
//
//   control  measured box (board frame)              -> cutout centre (case frame)
//   -------  --------------------------------------  ----------------------------
//   MENU     X -15.000..-7.300  Y -5.10..-1.60        y = -11.150   z = 8.350
//   EXIT     X   7.300..15.000  Y -5.10..-1.60        y = +11.150   z = 8.350
//   ROTARY   X  -6.582.. 6.582  Y -3.80..-1.00        y =   0.000   z = 9.300
//   USB-C    Z  -3.870.. 5.070  Y -4.81..-0.61        x =  +0.600   z = 8.990
//   BOOT     Z  11.450..18.950  X -14.175..-9.625     x = +15.200   y = -11.900
//   RESET    Z  21.920..29.420  X -14.175..-9.625     x = +25.670   y = -11.900
//
//   (z = PCB_FACE_Z + midpoint of the Y span, PCB_FACE_Z = 11.700.
//    e.g. MENU: 11.700 + (-5.10 + -1.60)/2 = 11.700 - 3.350 = 8.350.)
//
//  Independent cross-check, measured off docs/images/hardware-overview.webp by
//  pixel analysis (board outline = scale reference, 13.85 px/mm):
//
//   control  photo                     STEP        delta
//   -------  ------------------------  ----------  --------
//   MENU     board X -11.16            -11.150     0.01 mm
//   EXIT     board X +11.16            +11.150     0.01 mm
//   ROTARY   board X span 13.29 wide    13.164     0.13 mm
//   ROTARY   protrudes 2.1..2.7 past the edge (2.749 in STEP)
//   MENU/EXIT protrude 0.83 past the edge (0.80 in STEP)
//   BOOT     board Z +15.23            +15.200     0.03 mm
//   RESET    board Z +25.60            +25.670     0.07 mm
//   USB-C    board Z + 0.40             +0.600     0.20 mm
//   BOOT/RESET board X -12.24/-12.28   -11.900     0.35 mm (cap vs. body
//              centre; the pinholes are oversized to absorb this)
//
//  ============================================================================
//  CORRECTION TO reference/BOARD_GEOMETRY.md: THE BOARD HAS NO MOUNTING HOLES
//  ============================================================================
//  BOARD_GEOMETRY.md reported "4 x Ø2.00 mm mounting holes at (+/-14.60,
//  +/-30.60), 1.00 mm from both nearest edges". Those cylindrical faces are
//  real, but they are not holes — they are the PCB outline's CORNER FILLETS:
//
//    * A Ø2.0 hole whose centre sits exactly 1.0 mm from the edge would be
//      tangent to that edge, i.e. it would break out of the board. Not
//      manufacturable.
//    * R1.0 centred 1.0 mm in from both edges at all four corners is the exact
//      signature of a 1 mm corner round, and the product photo shows rounded
//      corners of about that radius.
//    * Three of the four positions sit underneath the MENU and EXIT switch
//      bodies (MENU spans board X -15.000..-7.300 at Z -32.400..-28.900, which
//      contains (-14.60, -30.60)) — impossible for a screw hole.
//    * The remaining "2 x Ø1.00 mm holes at (+/-7.00, 30.30)" are the rounded
//      ends of the FPC pass-through SLOT, ~14.0 x 1.0 mm at board Z = 30.30.
//      The slot is plainly visible in the product photo at that exact spot.
//    * Elecrow's own wiki lists no mounting holes, and none are visible
//      anywhere on the component-side photo.
//
//  So there are no PCB screw points, and this enclosure does not pretend there
//  are. The board is CLAMPED instead: it rests on a 0.8 mm perimeter ledge in
//  the back shell and is held down by a matching rib on the front frame,
//  directly opposite. Both are interrupted wherever a measured component would
//  foul them (see KEEPOUTS). The two case halves screw to each other through
//  the thickened long walls, entirely outside the PCB footprint.
//
//  ============================================================================

$fn = 48;

// ---------------------------------------------------------------------------
// 1. MEASURED BOARD DATA  (board frame, millimetres, from the STEP assembly)
// ---------------------------------------------------------------------------

PCB_W  = 31.2;    // board X span, -15.60 .. +15.60
PCB_L  = 63.2;    // board Z span, -31.60 .. +31.60
PCB_T  =  2.1;    // board Y span,  -2.10 ..   0.00
PCB_CORNER_R = 1.0;   // outline corner fillet (see the correction note above)

// e-paper module (2_13-LCD): sits on the display face and stands 0.90 mm proud.
GLASS_W  = 29.2;  // board X, -14.60 .. +14.60  -> 1.0 mm of PCB margin each side
GLASS_L  = 59.2;  // board Z, -29.60 .. +29.60  (the STEP bbox runs to +30.448;
                  //   that extra 0.85 mm is the FPC tail, not glass)
GLASS_H  =  0.9;  // board Y,   0.00 ..  +0.90
// Active area: NOT in the STEP file. 122 x 250 pixels at the panel's 0.1942 mm
// pitch => 23.71 x 48.55 mm. Its offset within the glass is also not measured,
// so the frame aperture below is deliberately oversized to absorb it.
ACTIVE_W = 23.71; // board X
ACTIVE_L = 48.55; // board Z

// Measured part bounding boxes, board frame: [Xmin, Xmax, Ymin, Ymax, Zmin, Zmax]
MENU_BOX   = [-15.000,  -7.300, -5.100, -1.600, -32.400, -28.900];
EXIT_BOX   = [  7.300,  15.000, -5.100, -1.600, -32.400, -28.900];
ROTARY_BOX = [ -6.582,   6.582, -3.800, -1.000, -34.349, -25.350];
BOOT_BOX   = [-14.175,  -9.625, -8.100, -1.584,  11.450,  18.950];
RESET_BOX  = [-14.175,  -9.625, -8.100, -1.584,  21.920,  29.420];
USBC_BOX   = [  7.700,  15.600, -4.810, -0.610,  -3.870,   5.070];
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

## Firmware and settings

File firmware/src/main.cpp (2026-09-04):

#include <Arduino.h>
#include <LittleFS.h>
#include <esp_random.h>

#include "battery.h"
#include "config.h"
#include "input.h"
#include "library.h"
#include "renderer.h"
#include "settings.h"
#include "ui.h"
#include "web_server.h"
#include "wifi_setup.h"

namespace {
Renderer renderer;
}  // namespace

void setup() {
  Serial.begin(115200);

  // Nothing drives this pin unless firmware does — the board doesn't light it on its
  // own just from having power. On solid for as long as the device is running.
  pinMode(PIN_STATUS_LED, OUTPUT);
  digitalWrite(PIN_STATUS_LED, HIGH);

  input::begin();
  // LittleFS::begin()'s partitionLabel defaults to "spiffs" — a holdover from when the
  // library shared code with SPIFFS. firmware/partitions.csv labels the data partition
  // "littlefs" (see its own header comment), so the default silently mounted nothing:
  // LittleFS.begin() would find no matching partition and every file operation failed,
  // undetectable by a compile and invisible in the simulator, which never touches real
  // flash — this only ever showed up running on actual hardware.
  LittleFS.begin(true, "/littlefs", 10, "littlefs");
  settings::begin();
  renderer.begin();
  randomSeed(esp_random());  // games otherwise deal the same "random" board every boot

  // Hold MENU while powering on to re-enter WiFi setup.
  bool forcePortal = (digitalRead(PIN_MENU_BUTTON) == LOW);

  renderer.renderStatusLine("Connecting to WiFi...");
  wifi_setup::begin(forcePortal, [](const String& ip) {
    // Printed directly rather than relying on ereader.local — see wifi_setup.h.
    String status = "Connect at: " + ip;
    int pct = battery::readPercent();
    // -1 until PIN_BATTERY_ADC in config.h is wired up — see battery.h.
    if (pct >= 0) status += "   Batt: " + String(pct) + "%";
    renderer.renderStatusLine(status);
    delay(2000);
  });

  // library:: and ui:: must be ready before the async server starts: an upload landing
  // between web_server::begin() and ui::begin() used to call ui::onLibraryChanged() ->
  // renderCurrent() while the renderer pointer was still null.
  library::begin();
  ui::begin(&renderer);
  web_server::begin([]() { ui::onLibraryChanged(); });
}

void loop() {
  wifi_setup::poll();

  // Drain the input queue rather than handling one event per iteration, so a fast
  // double-press isn't paced by the loop delay below.
  for (InputEvent e = input::poll(); e != InputEvent::None; e = input::poll()) {
    ui::handle(e);
  }

  ui::tick();

  // TODO(verify): once the ext1 wakeup pin set is confirmed on real hardware (input.h),
  // ui::tick()'s sleep path can hand off to input::enterLightSleepUntilInput() instead of
  // this poll-and-delay loop, which is what actually saves power between page turns.
  delay(20);
}

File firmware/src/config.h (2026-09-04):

#pragma once

#include <cstddef>  // size_t, for WALLPAPER_BYTES below

// Button/rotary GPIOs — from Elecrow's published pin table for the 2.13" HMI display.
// https://www.elecrow.com/wiki/CrowPanel_ESP32_E-Paper_2.13-inch_Arduino_Tutorial.html
static const int PIN_MENU_BUTTON = 2;
static const int PIN_EXIT_BUTTON = 1;
static const int PIN_ROTARY_DOWN = 4;
static const int PIN_ROTARY_UP = 6;
static const int PIN_ROTARY_CONF = 5;

// Display SPI pins — read off Elecrow's schematic (CrowPanel_ESP32_Display-2.13(E)_Inch.pdf,
// "EPD interface" block, matching the IO#_NAME net labels there — same naming convention as
// the button pins above, which that schematic independently confirms). Not yet continuity-
// tested against a physical board, so still worth a quick multimeter sanity check before
// relying on it, but this is a real schematic read, not a guess.
static const int PIN_EPD_MOSI = 11;  // IO11_SPI_MOSI -> SDA
static const int PIN_EPD_SCK = 12;   // IO12_SPI_CLK  -> SCL
static const int PIN_EPD_CS = 14;    // IO14_CS
static const int PIN_EPD_DC = 13;    // IO13_D/C
static const int PIN_EPD_RST = 10;   // IO10_RES
static const int PIN_EPD_BUSY = 9;   // IO9_BUSY

// The panel's 3.3V rail is separately gated (schematic: "IO7_LCD_3.3_CTL"), not just tied
// to always-on 3.3V — renderer.cpp must drive this high before display.init() or nothing
// will respond on the SPI lines above.
static const int PIN_EPD_POWER_CTL = 7;

// Driver chip: confirmed JD79661 on real hardware (2026-09-04) — GxEPD2's generic SSD1680
// class (GxEPD2_213_BN) hit a busy-wait timeout and never actually refreshed the panel.
// renderer.cpp uses GxEPD2_213c_GDEY0213F51 instead, GxEPD2's JD79661-specific driver.

// Power/status LED — schematic "IO19_LED", other terminal to ground, so this pin sources
// current through it: drive HIGH to light it, LOW to turn it off.
static const int PIN_STATUS_LED = 19;

// Panel geometry. Native resolution is 122x250 portrait, but that's only ~19
// characters/line — tedious to read. Rendered landscape instead (setRotation(1) in
// renderer.cpp transposes the draw surface; the physical panel and buttons don't move)
// for a ~40 char/line, ~10 line/page layout much closer to normal reading rhythm.
// Confirmed against simulator/index.html before committing to it here.
static const int PAGE_WIDTH_PX = 250;
static const int PAGE_HEIGHT_PX = 122;
static const int MARGIN_PX = 4;
static const int LINE_HEIGHT_PX = 11;
static const int HEADING_LINE_HEIGHT_PX = 14;

// Full refresh every N partial-refresh page turns, to clear e-ink ghosting.
// Tied to page turns (a counter), not a timer — see docs/ARCHITECTURE.md.
// Runtime-adjustable from the on-device Settings screen (unlike the layout constants
// above, which are baked into every .cebk at conversion time) — this default is just
// the starting value; settings::refreshEveryNPages() is what the renderer reads.
static const int FULL_REFRESH_EVERY_N_PAGES = 8;

// Menu/list screens. Mirrors simulator/index.html's LIST_TOP_MARGIN / LIST_LINE_H /
// LIST_FONT_PX so the on-device menus lay out the same way the simulator previews them.
static const int LIST_TOP_MARGIN_PX = 4;
static const int LIST_LINE_HEIGHT_PX = 12;
static const int LIST_FIRST_BASELINE_PX = LIST_TOP_MARGIN_PX + 8;

// Input gesture timing — matches bindHoldGesture()'s holdMs default in the simulator.
static const unsigned long HOLD_GESTURE_MS = 550;

// Idle sleep. 5 minutes while reading a page, 1 minute anywhere else — a menu sitting
// open is a much stronger idle signal than a page you may still be reading.
static const unsigned long IDLE_SLEEP_READING_MS = 5UL * 60UL * 1000UL;
static const unsigned long IDLE_SLEEP_MENU_MS = 60UL * 1000UL;

static const char* BOOKS_DIR = "/books";
static const char* WALLPAPER_DIR = "/wallpapers";
static const char* STATE_FILE = "/state.json";
static const char* WIFI_AP_NAME = "CrowPanel-Reader-Setup";

// A wallpaper is a raw 1-bit bitmap at the panel's native resolution, nothing else —
// see docs/FLASH_BUDGET.md "Wallpapers: cheap, by design".
static const size_t WALLPAPER_BYTES = (122 * 250) / 8;  // 3,813 B
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

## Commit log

2026-09-02 Initial commit: ESP32 e-paper EPUB reader with browser simulator
    Full project scaffold for a DIY EPUB reader on the CrowPanel ESP32
    2.13" E-Paper display: firmware, browser-side EPUB converter, a
    parametric enclosure, and an extensively-featured browser simulator
    (pagination, ghosting-accurate refresh, five games, wallpapers,
    memory accounting, ruler calibration) for previewing the device UI
    ahead of hardware arriving.
    [case.scad, partitions.csv]
2026-09-02 Remove battery indicator, add dithering controls and true-size display
    - Drop the illustrative battery percentage from the sleep screen and boot
    status line. The stock schematic has no battery sense line, so there was
    never a real reading to show; firmware already gated this correctly.
    - Wallpaper uploads now open a live dithered preview with Brightness,
    Contrast and Invert controls before committing, since a fixed threshold
    dithers dim or overexposed photos badly.
    - True-size calibration can now resize the actual interactive display, not
    just the inert preview box.
    - Add docs/SIMULATOR.md: full UI/UX reference (closes #1).
    - Add an in-app "About this project" panel with the AI-ass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
2026-09-02 Add annotated hardware overview image to the README
    Moves the loose product image out of the repo root into docs/images/
    and uses it to open a new "The hardware" section. The image is worth
    keeping because it independently corroborates two figures the project
    already depends on: the 63.19 x 31.2mm active area behind the
    simulator's true-size calibration, and the MENU/EXIT/rotary input trio
    the whole UI is built around.
    Also notes that the board's BAT connector is power-in only, with no
    voltage sense line to the MCU, which is why no battery indicator
    exists in the UI.
    Credited to Elecrow as their product image, in both the caption and
    the sources section.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
2026-09-02 Move project docs into a separate simulator/docs.html page
    The doc summaries were living inline in index.html's sidebar, pulled
    from GitHub for anything past the first paragraph. Split into a
    standalone simulator/docs.html instead: a hand-rolled markdown-to-HTML
    renderer (headings with anchor ids, lists, code fences, GFM tables)
    shows the full text of all four docs in-site, with a left-hand index
    to switch between them, so nothing sends readers out to GitHub anymore.
    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
2026-09-02 Rearchitect enclosure: cutouts on the right wall/piece, drop battery box
    The board photo (docs/images/hardware-overview.webp) shows MENU/Rotary/EXIT
    side-mounted on the PCB's left edge, GPIO_D/BOOT/RESET top-mounted on the top
    edge, and UART0/USB-C/BAT on the bottom edge -- none of them front-face. The
    old case.scad punched all its button/rotary/USB-C holes straight through
    front_frame's flat face, while back_shell (the only piece with real wall
    height) had zero cutouts. That's why nothing lined up: the holes were on the
    wrong piece, in the wrong plane.
    - back_shell() now owns the left-wall cutouts for MENU/ROTARY/EXIT (in that
    top-to-bottom order, rotary sized for real knob clearance) an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
    [case.scad]
2026-09-03 Fix firmware bugs found by a real build, and close the simulator parity gap
    The firmware never compiled: renderer.cpp called a GxEPD2 init() overload
    that doesn't exist. Building it for real (arduino-cli, ESP32 core 3.3.10)
    caught that plus a series of others:
    - Uninitialized reads on truncated .cebk files fed garbage offsets into
    seeks and reserve() calls; the reader now validates every table against
    the file size and refuses to open a book that fails.
    - Light sleep armed ext1 with ALL_LOW across five buttons, so waking it
    needed every button held at once. Now ANY_LOW, with pin validity checked.
    - input::poll() returned on the first pressed button, stalling the other
    buttons' debou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
    [book_format.h, config.h, input.cpp]
2026-09-03 Restructure the site: landing page, Web Serial installer, dither picker
    The site was a simulator with docs bolted on. It's now four pages: a
    landing page explaining what this is, the simulator at sim.html, a
    Web Serial installer, and the docs browser. All share a light/dark
    toggle that follows the OS until you choose otherwise.
    install.html flashes a connected ESP32-S3 from the browser via ESP Web
    Tools. The Pages workflow now builds the firmware with arduino-cli
    (core 3.3.10 — the toolchain it was actually verified against, and
    PlatformIO's official platform still ships core 2.x where the
    light-sleep API doesn't exist) and publishes the binaries alongside the
    site, so the manifest and .b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
2026-09-03 Measure the real board geometry from Elecrow's CAD assembly
    Every enclosure dimension so far was a guess, and it showed — the button
    cutouts landed on the wrong face twice. Elecrow publishes the actual
    Creo assembly; opening it in FreeCAD and querying per-part gives real
    numbers for the first time.
    The board is 31.2 x 63.2mm (the model guessed 40 x 82). Mounting holes
    are 2.0mm at (+/-14.6, +/-30.6), 1mm in from the edges — the model
    guessed 2.2mm at a 3mm inset, missing all four. MENU/rotary/EXIT are
    edge-mounted on one short edge and protrude past the board outline;
    BOOT/RESET aren't on an edge at all, they stick out the component face.
    Recorded in enclosure/reference/ with the extra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
2026-09-03 Don't let a firmware build failure take the website down
    The firmware build now runs with continue-on-error and the manifest step
    is gated on it succeeding. install.html already degrades to the
    build-from-source instructions when no binaries are published, so a
    broken firmware build costs the installer and nothing else — rather than
    blocking the docs and landing page from deploying at all.
2026-09-03 Confirm the flashed partition table matches partitions.csv
    PartitionScheme=custom would have silently fallen back to a stock table
    if the sketch-folder partitions.csv hadn't been picked up. Parsed the
    partitions.bin the workflow actually publishes: it's byte-for-byte the
    repo's table, so the 5.94MiB of book storage this doc's arithmetic
    assumes is what a flashed board really gets.
2026-09-03 Add robots.txt and a sitemap
    Rounds out the SEO metadata added with the site restructure. The
    firmware binaries are disallowed — they're multi-megabyte and have no
    business in a search index.
2026-09-03 Fix touch scroll on the simulator, and enlarge the homepage gallery
    Closes #3. Swiping the sim screen on a touchscreen fired MENU instead of
    scrolling. bindHoldGesture was switched to Pointer Events so mouse and
    touch could share one path, but the frame already had its own touch
    swipe handler — so every touch hit both. A swipe fired MENU (plus
    menu-hold if slow) *and* the scroll; a plain tap fired MENU twice.
    bindHoldGesture now cancels once the pointer travels past a 12px slop
    radius — a press that moves is a drag, not a press — and the touch
    handler no longer duplicates tap handling. Between the two thresholds
    (12px, 28px) is a deliberate dead band: ambiguous smudges do nothing
    rath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
2026-09-03 Rebuild the enclosure from Elecrow's measured CAD, not a product photo
    Every dimension in case.scad now comes from the STEP assembly extraction in
    enclosure/reference/, cross-checked by pixel analysis of the annotated product
    photo (the two agree to better than 0.4 mm on every control).
    What changed:
    - Board is 31.2 x 63.2 mm, not the 40 x 82 mm the file guessed.
    - MENU / rotary / EXIT cutouts sit at their measured X centres (-11.15, 0,
    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
    [case.scad]
2026-09-03 Fix touch input, rebuild the site as paper, add whole-library stats
    Touch, all from reports on a real phone:
    - Long-pressing MENU/EXIT sometimes did nothing and popped Android's
    word-selection overlay. Only .screen-frame had user-select/touch-action;
    the buttons and wheel didn't, so Android ran its own long-press gesture
    and the pointercancel that followed killed our hold timer.
    - Swipe direction was inverted. It used the content-scrolls-under-you
    model web pages use, which is right for a page of text and backwards
    for a cursor. The selection now follows your finger, and scrolling is
    continuous rather than one row per swipe.
    - "Swipe just scrolls the page" — .device now sets t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
2026-09-03 Add the whole-library reading stats screen to the firmware
    The simulator already had Home > Reading stats; the device didn't. This merges
    every book's per-day buckets into one timeline so the numbers answer "how much
    am I reading" rather than "how is this one book going" (which is what the
    existing per-book statsFor still does).
    Day 0 is the bucket used before the clock has ever been set. Its pages count
    toward the totals, since the reading really happened, but it's excluded from the
    streak, which needs real dates to mean anything. The streak walks back from
    today, starting at yesterday when today is still unread, so it isn't declared
    broken until a full day has actually been missed.
    Verif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
2026-09-03 Add an unlinked work-log page for tracking unattended work
    /secretupdates.html — no nav link, noindex, not in the sitemap. Just somewhere
    to point a browser at from another device to see what's in progress, queued,
    done, and any issues hit along the way while working through a longer backlog.
2026-09-03 Fix a boot-time crash risk and a stats-poisoning latch bug
    main.cpp started the async web server before library::begin()/ui::begin() ran.
    An upload landing in that window would call ui::onLibraryChanged() ->
    renderCurrent(), dereferencing the renderer pointer while it was still null.
    Reordered so library/ui are ready before the server starts accepting requests.
    Separately, BookReader::readOk_ was only reset in open()/close() — a single
    transient short read (or one out-of-range page/chapter request) latched it
    false permanently, silently blanking every page that BookReader ever rendered
    again for the rest of the session, not just the call that hit it. Reset it at
    the top of each public rea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
    [main.cpp]
2026-09-03 Website polish: favicon, 404 page, and accessibility fixes
    - Add a favicon (a simple ink document glyph, theme-adaptive via prefers-color-scheme)
    to all 5 pages. sim.html gets it inlined as a data URI rather than a relative link,
    since it ships standalone and has to render correctly with nothing alongside it.
    - Add a 404.html using the shared site.css shell, so a mistyped/stale link lands
    somewhere with a way back instead of GitHub Pages' default blank page.
    - sim.html's own header only linked Home and Docs, so a visitor who wants to flash a
    board next (the primary next step from the homepage's Try Now CTA) had to go back to
    Home first. Added an Install link alongside it.
    - input[t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
2026-09-03 Add on-device book delete
    docs/ARCHITECTURE.md lists list/delete as in-scope for on-device library management,
    but only the web API's /books/delete existed — there was no way to remove a book from
    the device itself.
    Adds library::remove(idx) (deletes the .cebk from LittleFS, then rescans so the
    in-RAM list and any carried-over state stay consistent with what's actually left)
    and a "Delete book" row in the BookMenu screen, guarded to only appear when browsing
    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
2026-09-03 Defer building the sample library until the boot sequence actually needs it
    BUILTIN_BOOKS was a top-level const holding ~800KB of pre-parsed book text as a
    single JSON literal — evaluating it (turning that literal into live objects/strings)
    happened synchronously as part of running the script, before anything later in the
    same script could run. That included bootSequence()'s own connect animation and every
    button becoming interactive, all blocked on constructing four books' worth of data
    whether or not the visitor ever looks at the sample library before loading their own
    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
2026-09-03 Fix three correctness bugs in the EPUB converter
    - extractChapterContent recorded style-run offsets against the untrimmed walked
    text, but returned text.trim(). A leading empty block (a page-break <div></div>
    before real content, which is common) leaves a leading '\n' that trim() drops
    without any corresponding shift to already-recorded runs[].offset — every style
    run in that chapter ends up pointing further into the text than the actual
    bold/italic span is. Now shifts every run's offset back by whatever trim()
    removed from the front, and clamps against the trimmed length so a run touching
    either edge can't end up describing text past what it should.
    - BinaryWriter.u16() wro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
2026-09-04 Fix three bugs found on first real hardware: LittleFS mount, WiFi hang, dead LED
    All three only ever showed up running on actual hardware — none catchable by a compile
    or exercisable in the simulator, which never touches real flash, real NVS, or real GPIOs.
    - LittleFS.begin(true) defaults its partitionLabel to "spiffs" (a holdover from when the
    library shared code with SPIFFS). partitions.csv labels the data partition "littlefs".
    The filesystem was never actually mounting — every file operation silently failed.
    Pass the label explicitly.
    - wm.autoConnect() had no connect timeout. This board came from Elecrow with a stale
    WiFi credential already saved in NVS (SSID "888") — NVS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
    [config.h, main.cpp]
2026-09-10 Fix power-loss position bug, bump font size, rework sleep, add Wi-Fi QR transfer
    - library: persist which book is actually being read (setActiveBook/activeBookIndex,
    keyed by path) so a cold boot resumes the right book instead of guessing from
    title-sort order. Cuts the state-flush debounce from 30s to 1s so an unplug loses
    at most a second of progress.
    - renderer/config/converter: bump body/heading fonts one step (08->10pt etc.) and the
    matching line heights; mirrored into converter.js (both copies), the simulator, and
    dump_font_metrics.ino. Existing .cebk files need re-conversion.
    - input/ui/config: two-stage idle sleep — a short, invisible light-doze between
    keystrokes (the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
2026-09-10 Revert font size, add status LED heartbeat, close #12 (full refresh + MENU remap)
    - font size: on-device testing showed the bumped 10pt body font overflowed pages that
    had been paginated (in the shipped .cebk) against the old 8pt layout — revert
    renderer.cpp/config.h/both converter.js copies/simulator/dump_font_metrics.ino back
    to the original sizes so they match the books already converted.
    - status LED: was solid-on for the device's entire runtime (warmed the board for no
    functional reason). Now a heartbeat — 100ms on / 1s off — while awake, and off
    entirely while asleep, driven by ui::tick()/goToSleep() (main.cpp just sets the pin
    up and leaves it low at boot).
    - Closes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
